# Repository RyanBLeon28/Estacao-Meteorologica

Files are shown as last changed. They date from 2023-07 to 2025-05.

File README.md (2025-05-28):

<h1>Estação Meteorológica Microcontrolada</h1>

<div align="center">
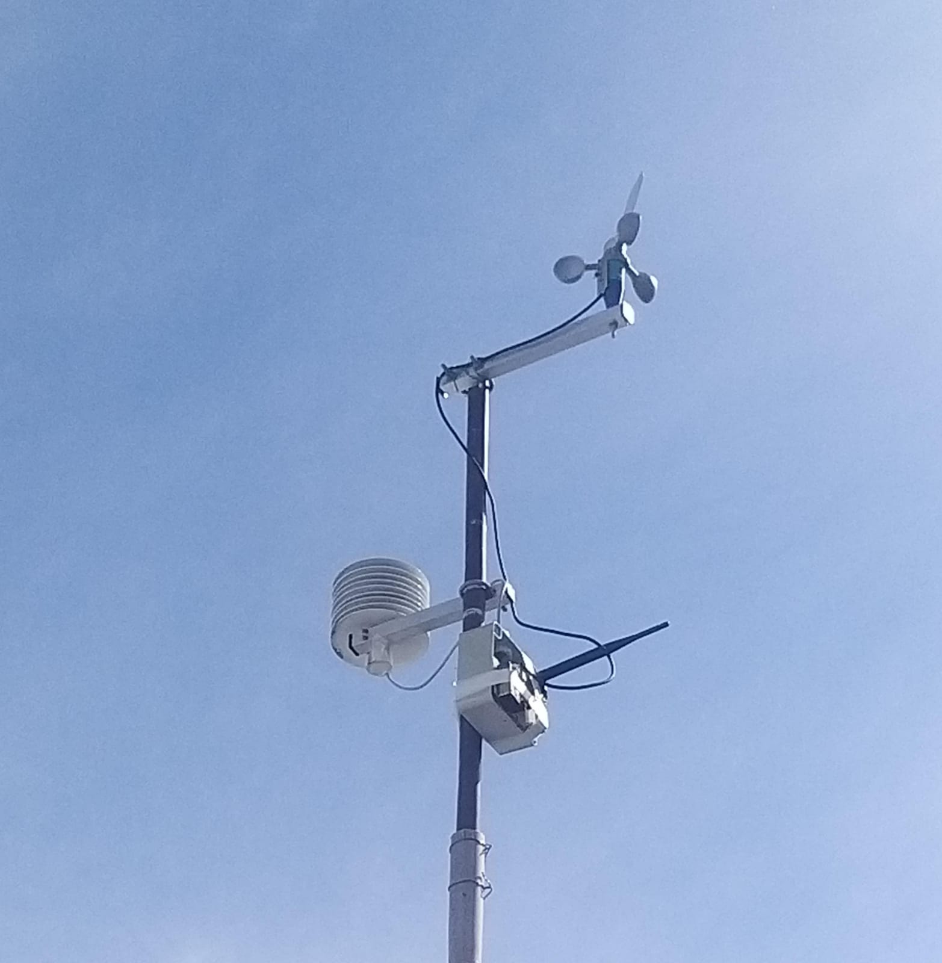
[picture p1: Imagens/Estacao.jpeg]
    
</div>

As estações meteorológicas são equipamentos utilizados para monitoramento e registro de condições climáticas por meio de sensores que analisam parâmetros atmosféricos como temperatura, umidade, pressão, velocidade e direção do vento. Neste projeto, os sensores estão conectados a um microcontrolador responsável por realizar a leitura dos dados. Esses dados são enviados automaticamente por protocolo LoRa(Long Range) para um servidor remoto (Datalogger), que realiza o armazenamento e processamento das informações.

O sistema foi projetado para operar continuamente e com baixo consumo de energia, sendo ideal para aplicações em ambientes externos. A visualização dos dados é feita por meio de dashboards acessíveis via navegador, possibilitando o acompanhamento em tempo real das variáveis monitoradas.

<h2>Tecnologias Utilizadas</h2>

<ul>
    <li><strong>MQTT (Eclipse Mosquitto):</strong> protocolo leve de comunicação utilizado para transmitir os dados dos sensores de forma eficiente e confiável.</li>
    <li><strong>Node.js:</strong> ambiente de execução utilizado no backend para processar as mensagens recebidas e integrá-las aos demais componentes do sistema.</li>
    <li><strong>Node-RED:</strong> ferramenta baseada em fluxo que facilita a criação de integrações entre os dados do MQTT e os bancos de dados utilizados.</li>
    <li><strong>InfluxDB:</strong> banco de dados especializado em séries temporais, utilizado para armazenar os dados dos sensores com alta performance.</li>
    <li><strong>Grafana:</strong> plataforma para visualização de dados que permite criar dashboards interativos e intuitivos para o acompanhamento das variáveis climáticas.</li>
</ul>

<h2>Detalhamento do projeto</h2>

<p>Para mais detalhes sobre o desenvolvimento da estação, incluindo a calibração de sensores como o anemômetro e a integração dos dados, consulte o <a href="Estação_Meteorológica_Microcontrolada.pdf" target="_blank">Relatório Descritivo do Projeto</a>.</p>

<h2>Referências</h2>

<p>
NODE.JS. Node.js. Disponível em: <a href="https://nodejs.org/en">https://nodejs.org/en</a>. Acesso em: 19 maio 2023.
</p>
<p>
MOSQUITTO. Mosquitto. Disponível em: <a href="https://mosquitto.org/">https://mosquitto.org/</a>. Acesso em: 19 maio 2023.
</p>
<p>
NODE-RED. Node-RED. Disponível em: <a href="https://nodered.org/">https://nodered.org/</a>. Acesso em: 19 maio 2023.
</p>
<p>
INFLUXDATA. Documentation. Disponível em: <a href="https://docs.influxdata.com/">https://docs.influxdata.com/</a>. Acesso em: 19 maio 2023.
</p>
<p>
GRAFANA LABS. Grafana. Disponível em: <a href="https://grafana.com/">https://grafana.com/</a>. Acesso em: 19 maio 2023.
</p>

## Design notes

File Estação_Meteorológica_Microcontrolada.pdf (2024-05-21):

Palavras-chave: Meteorologia, Anemômetro; IOT; DIY; Estação; Automatização.
INTRODUÇÃO
As estações meteorológicas são equipamentos para monitoramento e registro de condições climáticas com sensores configuráveis para análise de parâmetros atmosféricos e outras variáveis que afetam as rotinas meteorológicas. Os componentes podem ser: temperatura, umidade, pressão atmosférica, chuva, direção e velocidade do vento. Com os dados coletados e condições passadas, é possível calcular a probabilidade de eventos climatológicos de um futuro próximo.
A importância desses dados está ligada à previsão de como o clima pode se comportar em determinado local. Dessa forma, anteceder o que acontecerá é de extrema relevância, uma vez que se faz a necessidade em várias atividades humanas como a navegação, a aviação, a pesca, o setor energético, o gerenciamento de recursos hídricos, o turismo e a agricultura.
METODOLOGIA
O processo de coleta de dados acontece de forma automática - os sensores ligados a um microcontrolador receberão os dados e enviaram para um servidor (Datalogger). O modelo de estação automática no Brasil ainda é reduzido se comparado ao modelo convencional (um funcionário ir algumas vezes ao dia manualmente anotar os dados).
A parte instrumental do Anemômetro e Direção do vento foram produzidas em uma impressora 3D, a partir de um projeto pronto, adicionando rolamentos, imãs e parafusos.
Os sensores usados nesse projeto são, AS5600 (sensor de angulação), AH49E (sensor de efeito Hall), DTH11(sensor de temperatura e umidade) e BMP280 (sensor de pressão,altitude e temperatura).
Como microcontrolador, um ESP32 se comunica por protocolo MQTT com o servidor aberto, assim torna-se possível encaminhar e armazenar os dados coletados para um monitoramento remoto.

1


Figure 1: Estação meteorológica. Fonte:

2

## Contents

1 Instrumentação | 4
2 Gerenciamento dos Dados | 13

3

## 1 Instrumentação

### 1.1 Anemometro

Como o anemômetro é um instrumento para medir a velocidade do vento, o que garante sua precisão é de acordo com sua calibração. Para calibrarmos, utilizamos um anemômetro já calibrado, o Vaavud. Esse equipamento possui um aplicativo que detecta a passagem de um imã dentro do anemômetro. Como o celular possui um sensor magnético, consegue captar qual a frequência dos pulsos. Dessa forma, foi utilizado para servir de parâmetro para calibração.

### 1.1.1 Estrutura de Calibração

Para calibrarmos com o outro equipamento, montamos uma estrutura em impressora 3D em que os dois anemômetros ficassem no mesmo eixo. Como os estam presos no mesmo eixo, têm a mesma frequência angular. Sendo assim, usando um tacômetro DT-2234C capturamos a Rotação Por Minuto(RPM). Dessa forma, podemos ter a frequência angular, que pode ser usada para achar a velocidade do objeto.
Para a precisão da linearidade da velocidade e das amostras foi usado um motor, sendo controlado por um modulador PWM com 555.

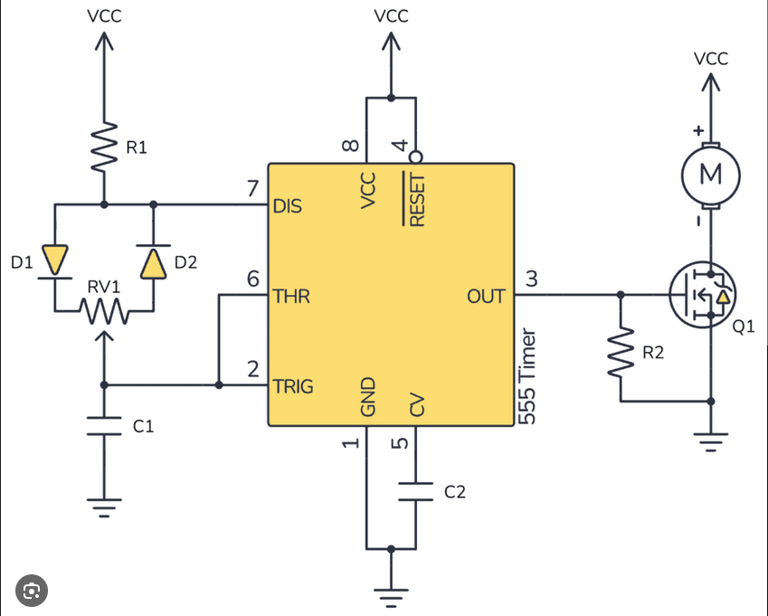
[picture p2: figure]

Figure 2: Modulador PWM com 555. Fonte:

Essa foi a primeira estrutura montada para começo da coleta de amostras. Com o decorrer das amostras, foi analisado a imprecisão, pois o Trimpot usado para controlar o DutyCicle, era simples e não tinhamos a mesma velocidade de saída para todas as amostras.

4

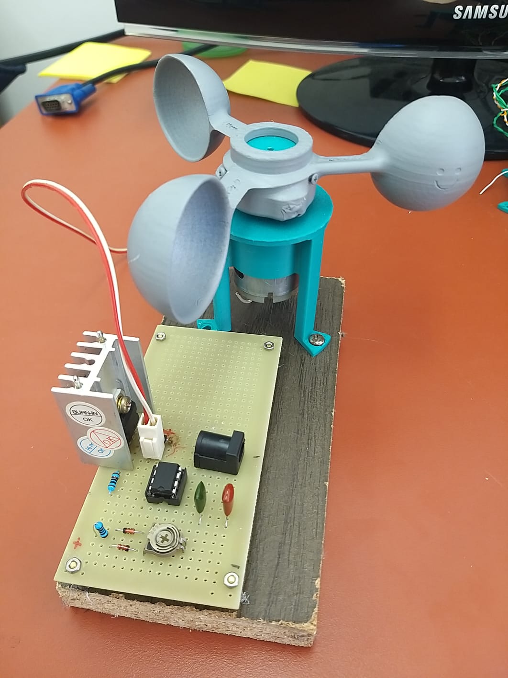
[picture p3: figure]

Figure 3: Modulador PWM com 555. Fonte:

Dessa forma, trocamos por um Trimpot de Precisão, de 0kOhm a 10kOhm. Dessa forma, controlamos a resistência que estava sendo aplicada e padronizamos isso durante a calibração.

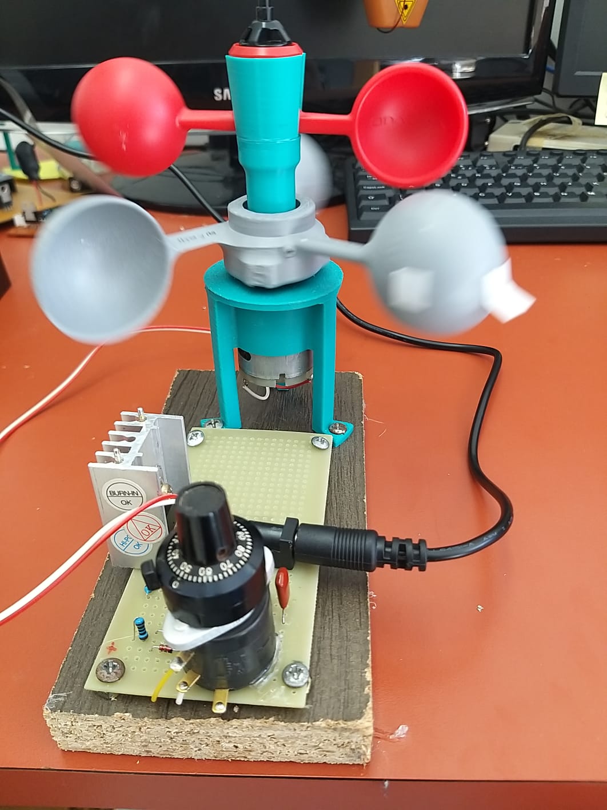
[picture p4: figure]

Figure 4: Modulador com o Trimpot de Precisão. Fonte:

5

### 1.1.2 Sensor Magnético

Para marcar a frequência do anemômetro, é utilizado um sensor magnético, que capta os pulsos de tensão de um imã, neste anemômetro há três imãs, um em cada pá. Nesse projeto, o sensor magnético escolhido foi o Sensor AH49E de efeito Hall (que descreve a geração de uma diferença de potencial elétrico (tensão) em um condutor quando uma corrente elétrica é aplicada perpendicularmente a um campo magnético externo).
Como o anemômetro possui três pás, são usados três imãs, no mesmo eixo das pás. E para contar um volta, é medido o número de pulsos e dividido pela quantidade de imãs.
Como o sensor de efeito Hall pode perder alguns dos pulsos ou não pegar com pouca intensidade o sinal, fizemos um sistema para que o sinal recebido fosse amplificado para uma leitura mais precisa. Sendo assim, foi desenvolvida uma PCB no software Kicad.

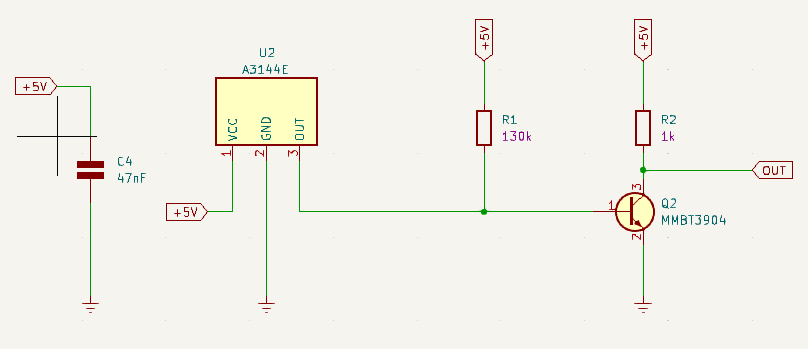
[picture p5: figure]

Figure 5: Esquemático sensor magnético. Fonte:

Figure 6: Visão 3D sensor magnético. Fonte:

6

### 1.1.3 Coleta de amostras

A coleta foi feita de forma manual com os seguintes passos, em um código python recebia a quantidade de amostras desejadas, em seguida, para a amostra de número um, inseria-se o valor da resistência utilizada no Trimpot, velocidade (em m/s no aplicativo do anemômetro do Vaavud), e cinco amostras de RPM refentes a essa resistência e velocidade. Sendo assim, com mais amostras era feita a média delas, para que fosse mais precisa.
Feita de forma mecânica e padronizando uma sequência na coleta para que as amostras obtidas tivessem as mesmas condições.
A imagem a seguir mostrar como eram feitas as coletas. O celular estava marcando a velocidade em m/s do anemômetro Vaavud, e com o tacômetro era lida a RPM.

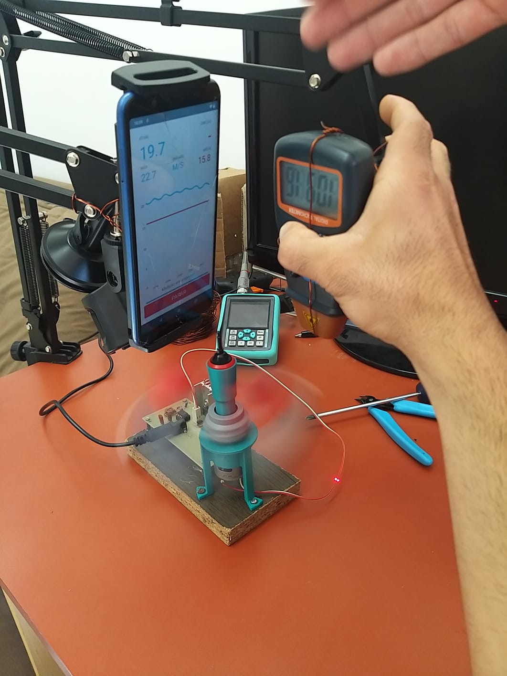
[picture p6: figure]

Figure 7: Coleta de amostras. Fonte:

Como os dados podiam sofrer alguma alteração, pois ao apertar com a mão o tacômetro e o tempo de leitura e angulação do laser na fita poderiam mudar, para que isso melhorasse, usamos um botão externo para acionar o tacômetro e para valor regulado do Trimpot de precisão, recebia uma leitura da velocidade e cinco amostras de RPM, tentando manter o mesmo padrão, entre visualizar e digitar.

7

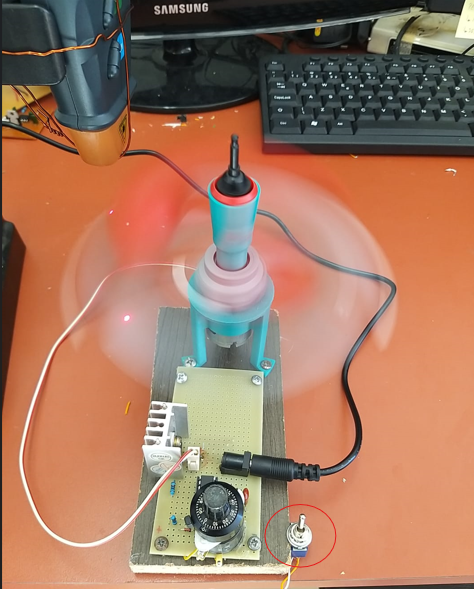
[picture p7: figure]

Figure 8: Tacômetro dom botão. Fonte:

### 1.1.4 Tratamento dos dados

Como citado anteriormente, os anemômetros estão girando no mesmo eixo, dessa forma, possuem mesma velocidade e, consequentemente, mesma frequência angular.
Depois de uma coleta de 120 amostras (excluindo as amostras que foram coletadas antes da última versão da estrutura de calibração), entre 0m/s à 21m/s, tendo como valor mínimo de 25,60rad/s e como máximo 110,93rad/s, frequência angular média de 71,96rad/s e apresentou Desvio Padrão de 23,61. Portanto, como apresentou certa linearidade, não precisamos retirar valores que fossem muito extremos ou que fugissem da reta.
Com as amostras coletadas foi feita uma regressão linear, da velocidade em relação a frequência angular. O valor resultante da equação da reta da regressão linear: Velocidade = 0.17117843*(Frequência Angular) + 0.19744649996588137.

8

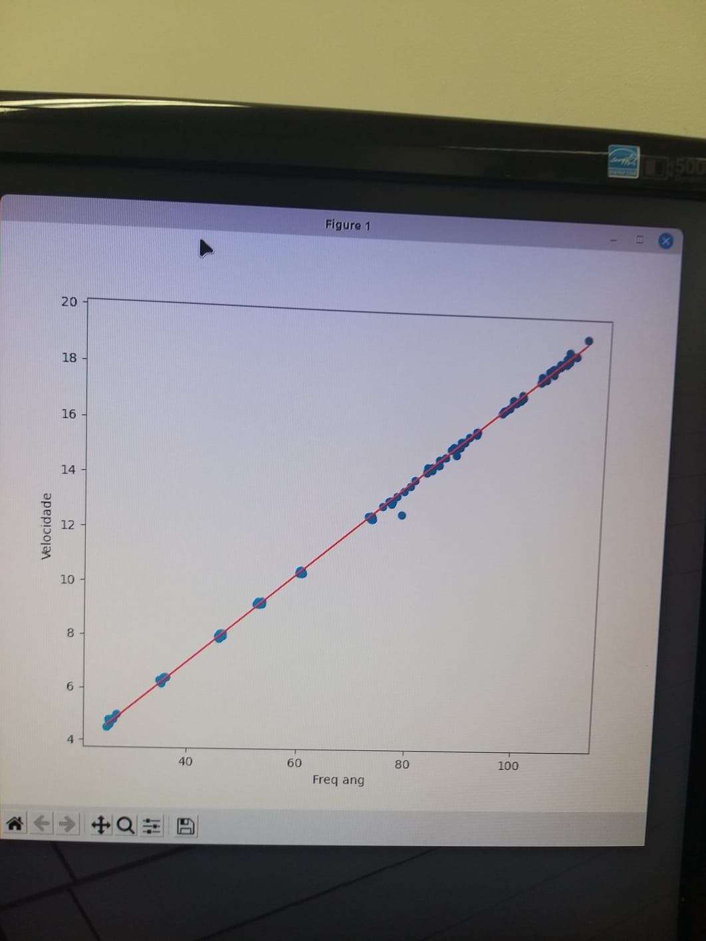
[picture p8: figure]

Figure 9: Regressão linear entre frequência angular e velocidade. Fonte:

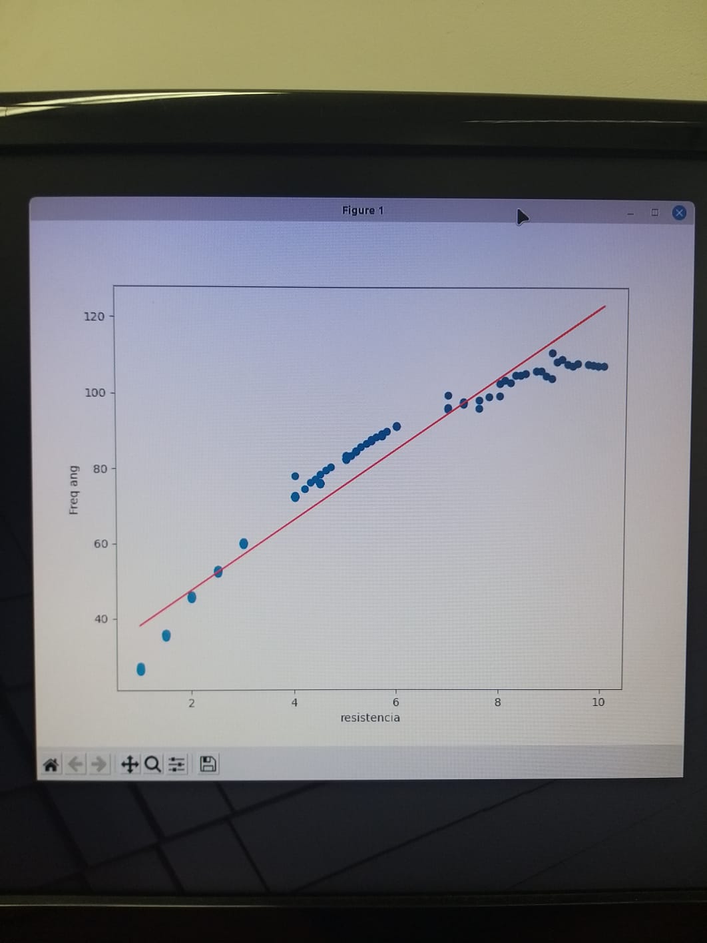
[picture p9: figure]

Figure 10: Regressão linear entre resistência e frequência angular. Fonte:

### 1.1.5 Resultados do Anemômetro

Com o resultado da regressão linear, obtendo o Rotação Por Minuto (RPM) é possível calcular a frequência angular e, assim, a velocidade em m/s. O código usado para o tratamento da coleta de pulsos com o sensor de

9

efeito Hall, está disponibilizado em nosso github. Explicando breviamente o código, é feita uma interrupção em uma porta digital do arduino quando a uma borda de subida, ou seja, um pulso elétrico captado pelo sensor. A cada três pulsos é contado como uma volta completa.
Para suavização das amostras, pode ser definido a quantidade de amostras que será feita a média da velocidade. Assim, há uma vetor tem tamanho definido conforme a quantidade inserida como máximo de amostras.
Na imagem a seguir, é mostrado o arduino Nano mostrando o RPM em um display Oled, colocados na mesma PCB em que é controlado o motor para velocidade do anemômetro.

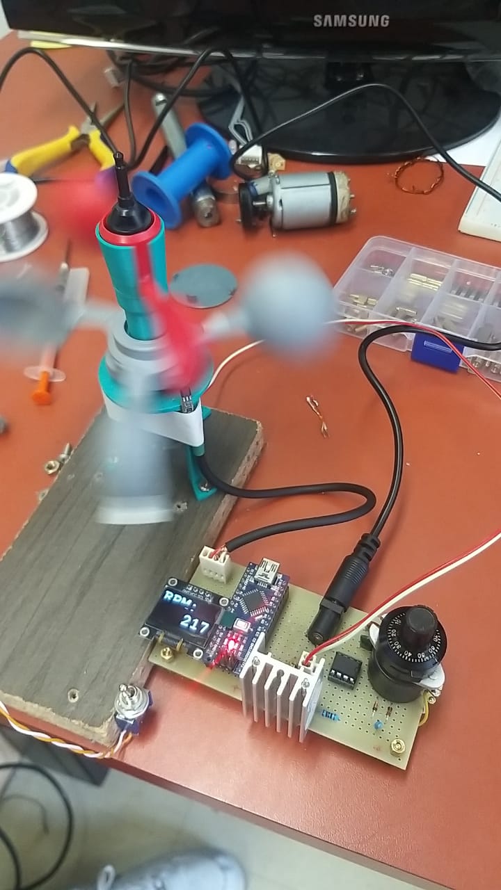
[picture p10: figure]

Figure 11: . Fonte:

10

### 1.2 Sensores

Além do sensor magnético, foram usados sensores para outros dados meteorológicos, como temperatura, umidade, pressão e altitude.Para temperatura e umidade o sensor DHT11, usando sinal digital em sua saída. E, também, o sensor BMP280 como objetivo principal, medir a pressão atmosférica, e com base nesses dados determinar com precisão a altitude de um ambiente, além de ser capaz de medir temperatura, este utiliza comunicação I2C.

### 1.3 Microcontrolador

Como microcontrolador usamos o Arduino Uno para calibração do anemômetro e alguns testes rápidos, pela versatilidade, compatibilidade e abundância de recursos que essa placa entrega.
Como a estação pode estar em lugares remotos, para enviar seus dados é necessária a comunicação com a internet, sendo assim, usamos o microocontrolador ESP32, que já possui wifi e bluetooth integrado. Além de outras vantagens em relação ao Arduino Uno, como maior poder de processamento, tendo dois núcleos,clock significativamente maior e memória.

11

### 1.4 LoRa

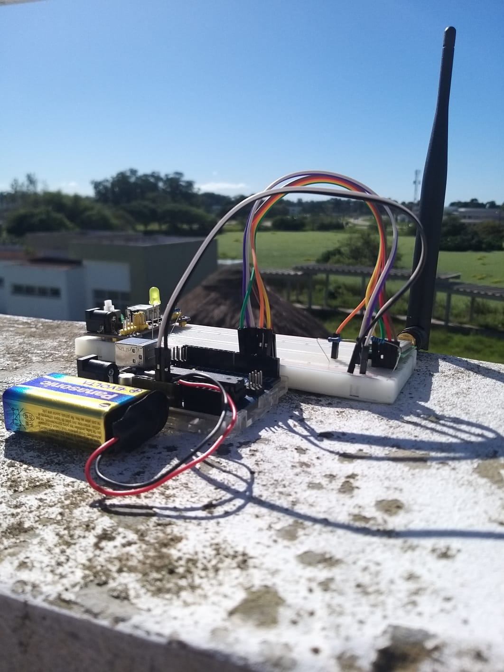
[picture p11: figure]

Figure 12: Estação meteorológica. Fonte:

Em alguns casos, podemos ter estações em lugares remotos, dessa forma, é importante haver uma comunicação estável e que não dependa de rede. Com isso, pode ser implementado a comunicação de radiofrequência. Nesse caso, a comunicação LoRa(Long Range) com longo alcance e baixa potência, projetada para aplicações de Internet das Coisas(IOT) e M2M(Machine-to-Machine). A vantagem dessa tecnologia é o baixo consumo de energia, umas de suas funções, apesar do baixo consumo, é a capacidade de ativar o modo Sleep (dormir) e quando solicitado voltar a funcionar e enviar os dados solicitados. Isso se torna ainda mais eficaz quando é usado o módulo LoRa para aplicações alimentadas por baterias.
Há vários modelos no mercado com muitas possibilidades de alcances, para o projeto usamos o módulo LoRa, o módulo usado é o modelo E220-900T22D, com capacidade de até 5km e frequência de 900MHz.
Por exemplo, uma estação com um microcontrolador arduino Nano coletar as informações dos sensores e enviar via LoRa para uma estação também com LoRa e um ESP32 que tem Wifi integrado para mandar os dados para o banco de dados na nuvem.
No projeto estamos enviando uma estrutura com os dados coletados em uma estação e sendo enviados para outra, como no exemplo anterior.

12

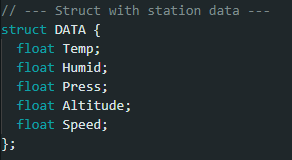
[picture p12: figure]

Figure 13: Estrutura sendo enviada via LoRa.

## 2 Gerenciamento dos Dados

Para que a estação meteorológica seja automatizada, precisa que seus dados sejam tratados e armazenados em algum lugar. Então, mesmo a estação estando em lugares remotos ou não, há a necessidade de que esteja preparada para enviar seus dados por meio de algum protocolo para um banco de dados. Dessa forma, essas informações podem ser usadas em previsões climáticas futuras.

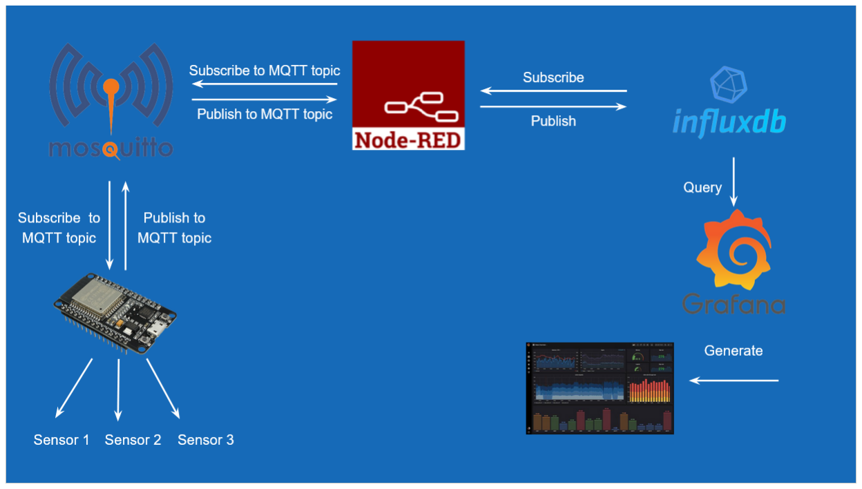
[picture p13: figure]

Figure 14: Esquemático do gerenciamento entre as aplicações.

### 2.1 Conexão MQTT

Após os dados estarem no microcontrolador, com a função de wifi do ESP32, usamos o protocolo de comunicação MQTT(Message Queuing Telemetry Transport) é um protocolo de mensagens leve e eficiente, projetado para comunicação entre dispositivos em redes de IoT (Internet das Coisas) ou em redes de comunicação com largura de banda limitada. Desenvolvido pela IBM nos anos 1990, o MQTT tornou-se um padrão aberto e é amplamente utilizado em uma variedade de aplicações IoT devido à sua simplicidade, eficiência e confiabilidade.
Usar um Broker MQTT facilita a comunicação entre dispositivos na arquitetura de mensagens, pois atua como um intermediário centralizado na comunicação entre dispositivos. Ademais, o gerenciamento de tópicos, broker MQTT

13 facilita o gerenciamento de tópicos e assinaturas. Ele permite que os dispositivos publiquem mensagens em tópicos específicos e que outros dispositivos subscrevam a esses tópicos para receber as mensagens. Isso simplifica a organização e o controle da comunicação em uma rede de dispositivos.
No contexto apresentado, utilizamos o broker Mosquitto, um servidor MQTT de código aberto. Desenvolvido pela Eclipse Foundation, o Mosquitto é reconhecido como uma escolha amplamente adotada para implementações de IOT e outras aplicações que requerem comunicação baseada nesse protocolo.

14

### 2.2 Node Red

O Node Red é um software para programar por meio de fluxogramas, utilizando Nodejs. Usa-se nodos para conectarem entre si.

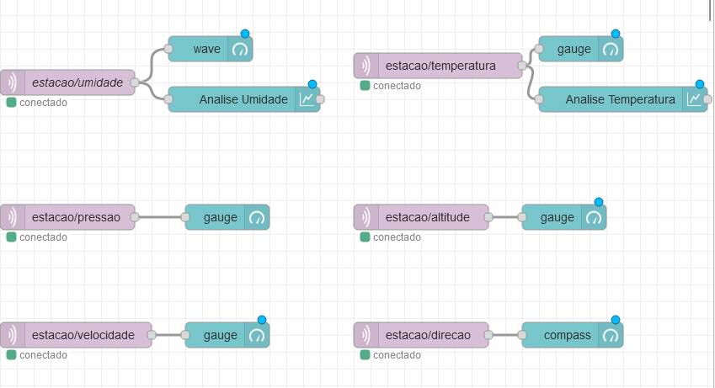
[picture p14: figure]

Figure 15: Nodos Node Red. Fonte:

Para configurar a comunicação com o banco de dados Influxdb e para criar uma dashboard do próprio Node Red, foram adicionadas as paletas nodered-contrib-influxdb e node-red-dashboard.
Como servidor foi usado o test.mosquitto.org:1883, esse é o servidor aberto do Broker Mosquitto. Como é um servidor aberto para uso de protocolo MQTT, o site recomenda não ser usado para aplicações grandes, porém, se for necessário maior resposta e do servidor, recomendasse utilizar um servidor privado.
O Tópico é o nome que será usado para acessar a informação publicada. Como exemplo, estação/temperatura.

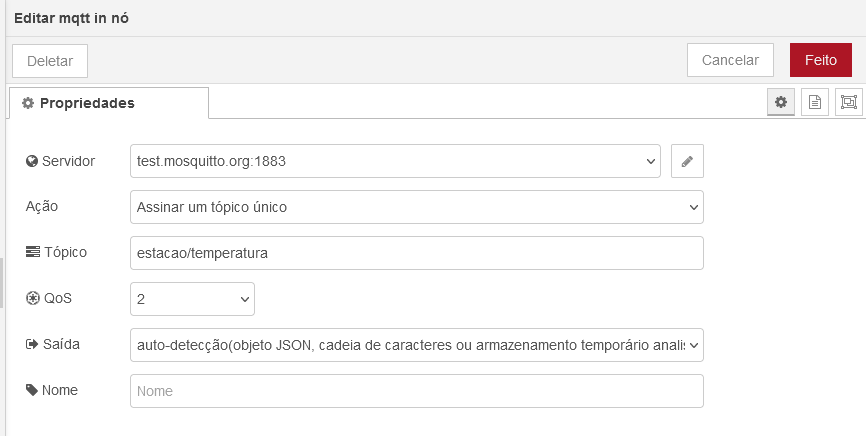
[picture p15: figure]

Figure 16: Configurando tópico Node Red. Fonte:

### 2.3 Influxdb

O InfluxDB foi o banco de dados usado para armazenamento das informações. Muito utilizado para series temporais, o InfluxDB se encaixa muito bem para controlarmos os dados da estação meteorológica.
O banco de dados está rodando localmente na porta 8086 de um computador com sistema operacional linux, MINT 21.3.

15

### 2.3.1 Instalar InfluxDB

Para instalar o InfluxDB em sua máquina, use os seguintes comando no seu terminal:

Para instalar o InfluxDB:
$curl -O https://download.influxdata.com/influxdb/releases/influxdb22.7.6− 1amd64.deb
$sudodpkg − iinfluxdb22.7.6 − 1amd64.deb

Para rodar o InfluxDB:
$influxd
O programa já estará rodando localmente, em seu navegador acesse: htpps://localhost:8086/

### 2.3.2 Configuração do InfluxDB

Em seu perfil criará uma Organization, depois será necessario gerar um Token para dar permição ao Node-Red enviar os dados. Após ter o token, crie um Bucket, local onde ficarão os dados recebidos, no nosso exemplo o nome do Bucket é estacaoMeteorologica.

16

### 2.4 Grafana

Para instalar o Grafana em sua máquina, use os seguintes comando no seu terminal:

Para instalar o Grafana:
$ sudo apt update
$ sudo apt-get install -y adduser libfontconfig1 musl
$ wget https://dl.grafana.com/enterprise/release/grafana-enterprise10.4.2amd64.deb $sudodpkg − igraf ana − enterprise10.4.2amd64.deb
$sudosystemctlenablegraf ana − server
$sudosystemctlstartgraf ana − server

Para checar se está tudo dando certo:
O programa já estará rodando localmente, em seu navegador acesse: htpps://localhost:3000/

A dashboard para vizualição pode ser personalizada.

17

Referências:
NODE.JS. Node.js. Disponível em: https://nodejs.org/en. Acesso em: 19 maio 2023.
MOSQUITTO. Mosquitto. Disponível em: https://mosquitto.org/. Acesso em: 19 maio 2023.
NODE-RED. Node-RED. Disponível em: https://nodered.org/. Acesso em: 19 maio 2023.
INFLUXDATA. Documentation. Disponível em: https://docs.influxdata.com/. Acesso em: 19 maio 2023.
GRAFANA LABS. Grafana. Disponível em: https://grafana.com/. Acesso em: 19 maio 2023.

18

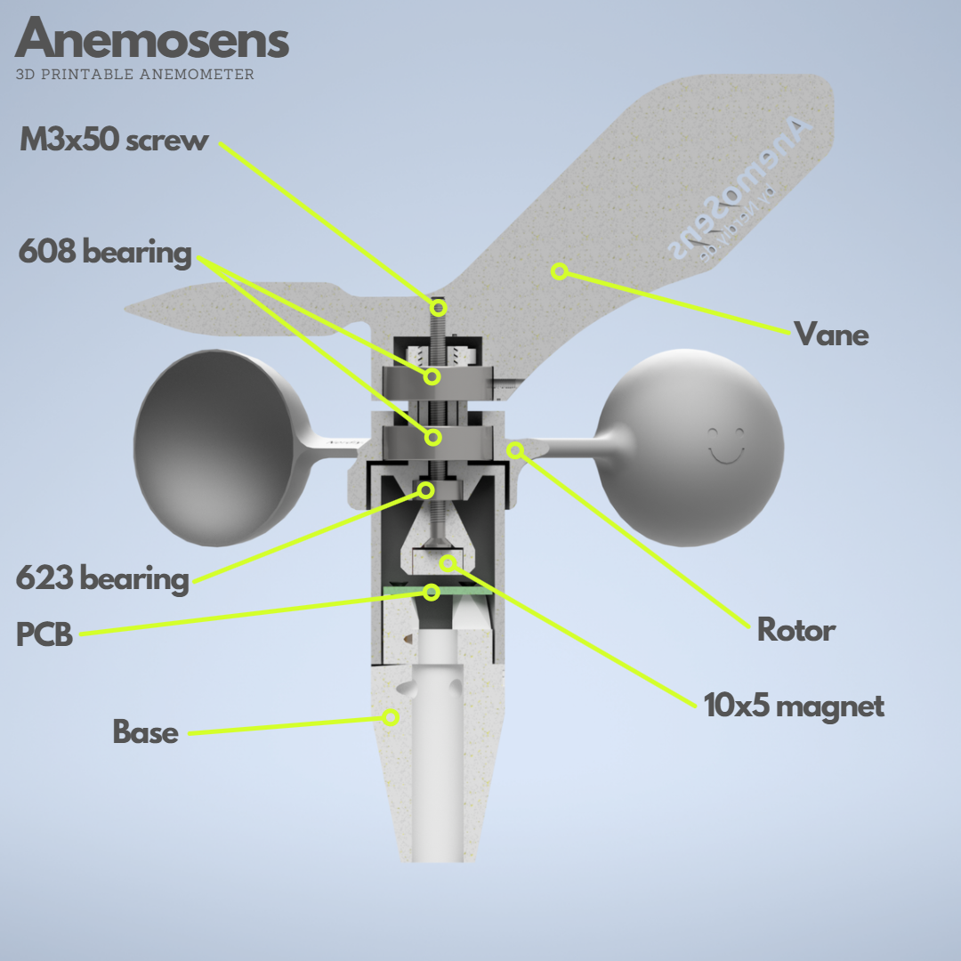
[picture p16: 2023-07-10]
Anemometro/Sensor de Efeito Hall PCB/Anemosens-main/pictures/Anemosens_overview.png

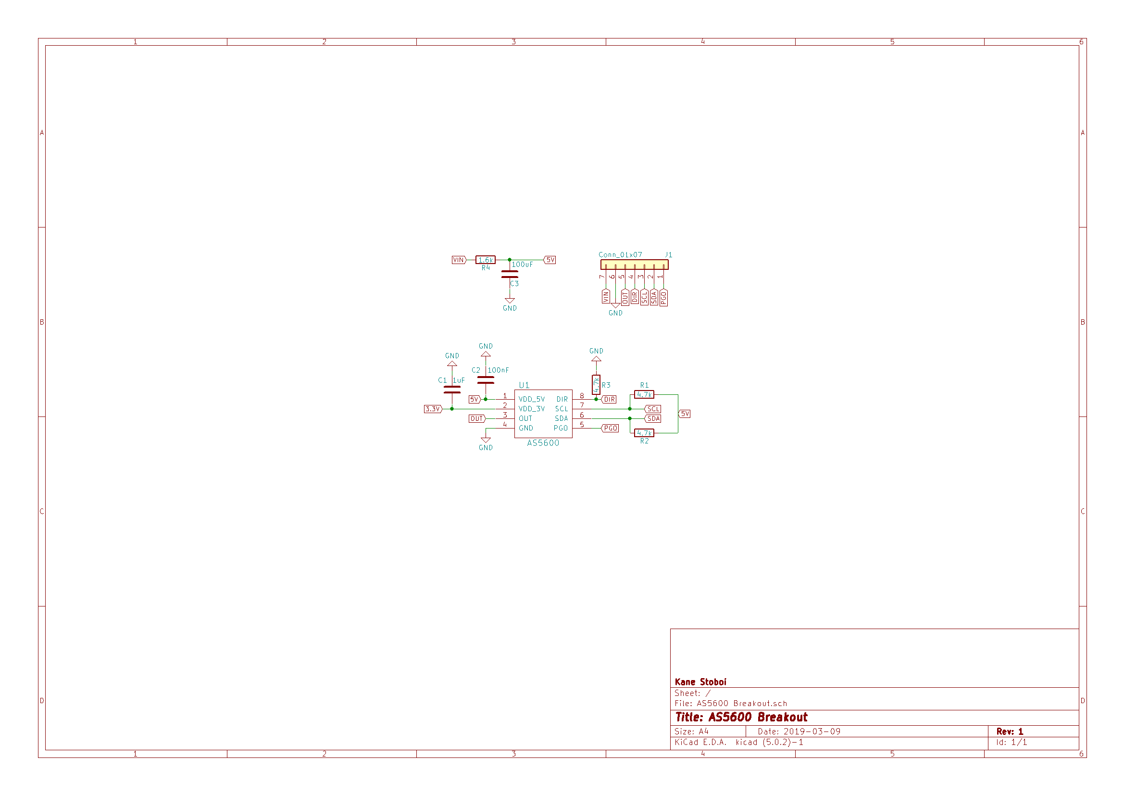
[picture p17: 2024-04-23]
Sensores/SensorAS5600/AS5600_PCB/AS5600 Board Schematic.png

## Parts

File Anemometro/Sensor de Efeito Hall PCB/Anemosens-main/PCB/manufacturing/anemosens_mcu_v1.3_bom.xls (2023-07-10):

PCBWay Bom Quotation, Product No.:T-1C4W457044A
Item # | *Designator | *Qty | Manufacturer | *Mfg Part # | Description / Value | *Package/Footprint | *Unit Price(5 sets) | *Total | *Delivery Time | *Actual Purchase Mfg Part # | *PCBWay Note | Customer Reply | PCBWay Update | Comment
1 | C2,C3,C9,C10,C102,C107,C125 | 7 |  |  | 100nF | C0805K | $0.031 | $1.085 |  | CL21B104KCFNNNE | 『 』
2 | C47,C48,C101,C103 | 4 |  |  | 1µF | C0805K | $0.029 | $0.580 |  | CL21B105KBFNNNE | 『 』
3 | C1,C6 | 2 |  |  | 10uF | C0805K | $0.060 | $0.600 |  | CL21A106KOQNNNE | 『 』
4 | C7,C8 | 2 |  |  | 22pF | C0805K | $0.074 | $0.740 |  | CL21C220JBANNNC | 『 』
5 | C11 | 1 |  |  | 1nF | C0805K | $0.242 | $1.210 |  | CL21C102JBCNNNC | 『 』
6 | R1,R7 | 2 |  |  | 10k | R0805W | $0.030 | $0.300 |  | RC0805FR-0710KL | 『 』
7 | R4,R6 | 2 |  |  | 5,1k | R0805W | $0.031 | $0.310 |  | RC0805FR-075K1L | 『 』
8 | R10,R11 | 2 |  |  | 66 | R0805W | $0.031 | $0.310 |  | RC0805FR-0766RL | 『 』
9 | R13,R14 | 2 |  |  | 5k | R0805W | $0.031 | $0.310 |  | RC0805FR-075KL | 『 』
10 | R15,R16 | 2 |  |  | 4k7 | R0805W | $0.035 | $0.350 |  | RC0805FR-074K7L | 『 』
11 | R45,R47 | 2 |  |  | 470 | R0805W | $0.032 | $0.320 |  | RC0805FR-07470RL | 『 』
12 | R3 | 1 |  |  | 120 | R0805W | $0.066 | $0.330 |  | RC0805FR-07120RL | 『 』
13 | R12 | 1 |  |  | 12k | R0805W | $0.050 | $0.250 |  | RC0805FR-0712KL | 『 』
14 | D10 | 1 | MDD | SS34 | SS34 | SMADIODE | $0.110 | $0.550 |  |  | 『 』
16 | U36 | 1 |  | BME280 | BME280 | PSON65P250X250X100-8N | $7.700 | $38.500 |  |  | 『 』[Price is changing higher, final price should be subjected to the real price when order!] |  |  | Optional: Only needed if measurement of temperature, humidity and air pressure is needed
17 | U$22,U$23 | 2 |  |  | SMT2X4MMTACTILE_PUSH_BUTTON | SMT2X4MMTACTILE_PUSH_BUTTON |  |  |  |  | 『 』Please provide exact part number or component URL. |  |  | Optional: Only needed if programming of the ESP32 is done manually (not via the USB-C connection)
18 | U6 | 1 |  | MAX3485ESA+ | MAX3485ESA+ | SOIC127P600X175-8N | $1.470 | $7.350 |  |  | 『 』 |  |  | Optional: Only needed if communication via rs485/modbus is needed
19 | U34 | 1 |  | DS3232M | DS3232M | SOIC127P600X175-8N | $9.500 | $47.500 |  |  | 『 』[Price is changing higher, final price should be subjected to the real price when order!] |  |  | Optional: Only needed for Timekeeping if data logging on locally connected micro SD card is needed
20 | U1 | 1 |  | CH340G | CH340G | SOIC16 | $0.825 | $4.125 |  |  | 『 』
21 | U2 | 1 |  | UMH3N | UMH3N | SOP65P210X100-6N | $0.156 | $0.780 |  |  | 『 』
22 | U17,U20 | 2 |  | RT9013 | RT9013 | SOT23-5 | $0.417 | $4.170 |  | RT9013-33GB | 『 』
23 | U3 | 1 |  | ESP32-WROVER-B | ESP32-WROVER-B | XCVR_ESP32-WROVER-B_(16MB) | $5.360 | $26.800 |  | ESP32-WROVER-B(16MB) | 『 』[Price is changing higher, final price should be subjected to the real price when order!]
24 | Y1 | 1 |  | ABM8AIG-12.000MHZ-12-2Z-T3 | ABM8AIG-12.000MHZ-12-2Z-T3 | OSCSC320X250X100N | $1.308 | $6.540 | 7-10 Workdays |  | 『 』
25 | F1 | 1 |  | 1206L200PR | 4A | PTC-1206-WIDE |  |  |  |  | 『 』
26 | EXT1 | 1 |  | SM04B-SRSS-TB(LF)(SN) | MICROBUILDER_STEMMA_I2C_QT | JST_SM04B-SRSS-TB(LF)(SN) |  |  |  |  | 『 』
28 | IC2 | 1 | TECH PUBLIC | SRV05-4 | SRV05-4 | TSOP-6.PAC | $0.152 | $0.760 |  |  | 『 』
29 | J4 | 1 |  | USB4105_REVA | USB4105_REVA | GCT_USB4105_REVA | $1.059 | $5.295 | 7-10 Workdays | USB4105-GF-A | 『 』
30 | J2 | 1 |  | SM04B-SRSS-TB(LF)(SN) | SM04B-SRSS-TB(LF)(SN) | JST_SM04B-SRSS-TB(LF)(SN) | $0.260 | $1.300 |  |  | 『 』 |  |  | Optional: Only needed if communication via rs485/modbus is needed
31 | J1 | 1 |  | SM06B-SRSS-TB(LF)(SN) | SM06B-SRSS-TB(LF)(SN) | JST_SM06B-SRSS-TB(LF)(SN) | $0.552 | $2.760 |  |  | 『 』
32 | J6 | 1 |  | BC501SM-TR | BC501SM-TR | MPD_BC501SM-TR | $1.714 | $8.570 | 7-10 Workdays |  | 『 』
33 | J5 | 1 |  | MEM2067-02-180-00-A | TRANSFLASH-LOCK | TRANSFLASH-LOCK-SOCK |  |  |  |  | 『 』 |  |  | Optional: Only needed if data logging on a locally inserted sd card is needed.
 |  |  |  |  |  |  | All Total | $161.695

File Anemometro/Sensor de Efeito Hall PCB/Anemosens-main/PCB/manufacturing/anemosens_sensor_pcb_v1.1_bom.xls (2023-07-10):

PCBWay Bom Quotation, Product No.:T-1C6W457044A
Item # | *Designator | *Qty | *Mfg Part # | Description / Value | *Package/Footprint | *Unit Price(5 sets) | *Total | *Delivery Time | *Actual Purchase Mfg Part # | *PCBWay Note | Customer Reply | PCBWay Update | Comment
1 | C1,C7 | 2 |  | 100nF | C0805K | $0.032 | $0.320 |  | CL21B104KBCNNNC | 『 』
2 | C8 | 1 |  | 10uF | C0805K | $0.121 | $0.605 |  | CL21A106KOQNNNE | 『 』
4 | U1 | 1 | AS5048B-HTSP | AS5048B-HTSP | SOP65P640X120-14N | $9.718 | $48.590 | 7-10 Workdays |  | 『 』
5 | U2 | 1 | AH49E | AH49E | SOT91P240X105-3N | $0.228 | $1.140 |  |  | 『 』
6 | JP1,JP2 | 2 |  |  | 1X03 |  |  |  |  | 『 』Please provide exact part number or component URL. |  |  | Do not populate! This are solder pads only used for development purposes. (Same signals are available on J1)
7 | J1 | 1 | BM06B-SRSS-TB(LF)(SN) | BM06B-SRSS-TB(LF)(SN) | JST_BM06B-SRSS-TB(LF)(SN) | $0.437 | $2.185 |  |  | 『 』
 |  |  |  |  |  | All Total | $52.840

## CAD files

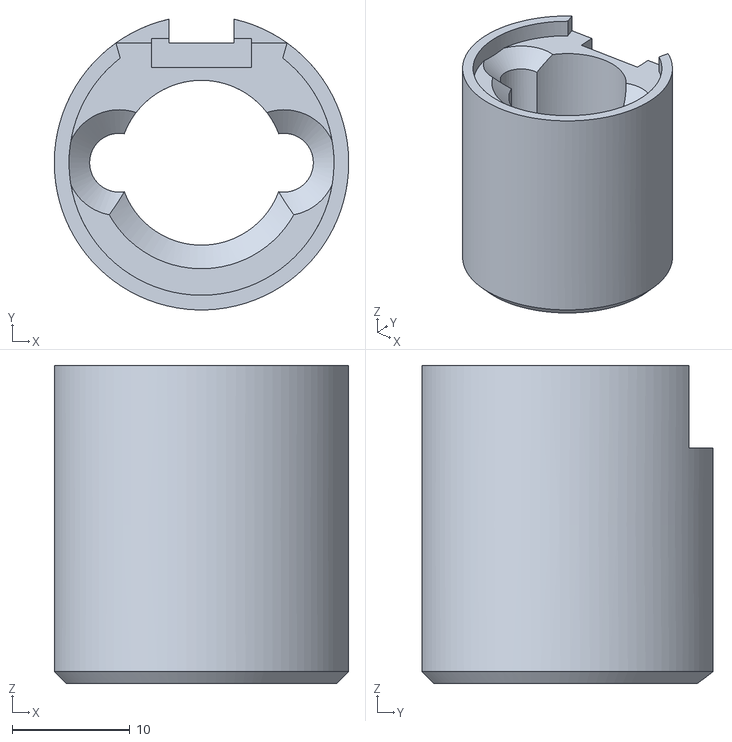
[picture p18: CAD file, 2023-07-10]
Anemometro/Sensor de Efeito Hall PCB/Anemosens-main/STLs/pcb_assembly_jig_V1.0.stl
25.0 x 24.7 x 27.0

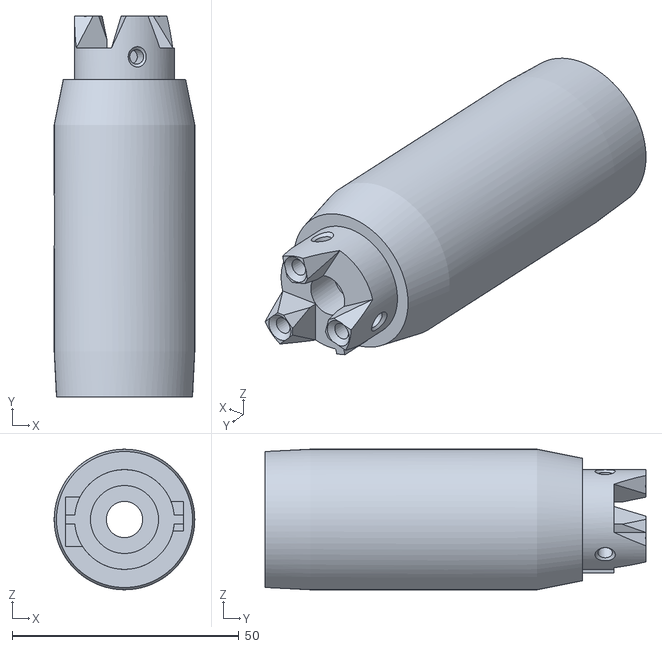
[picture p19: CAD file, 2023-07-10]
Anemometro/Sensor de Efeito Hall PCB/Anemosens-main/STLs/mount_base_mcu_board_V1.1.stl
31.0 x 84.0 x 31.0

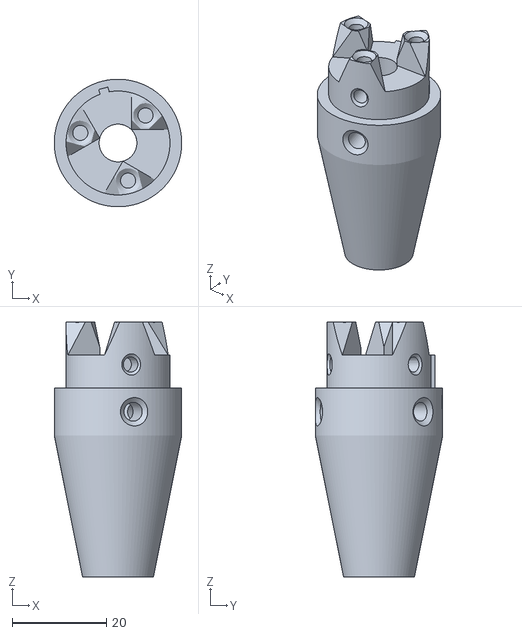
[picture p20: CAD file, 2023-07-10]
Anemometro/STLs/mount_base_10mm_pipe_fdm_printed_V1.0.stl
27.0 x 27.0 x 54.0

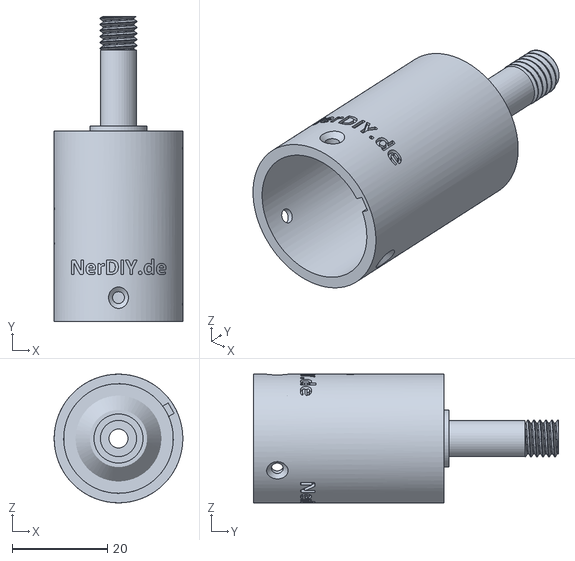
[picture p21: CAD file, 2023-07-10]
Anemometro/Sensor de Efeito Hall PCB/Anemosens-main/STLs/base_V1.1.stl
27.0 x 64.0 x 27.0

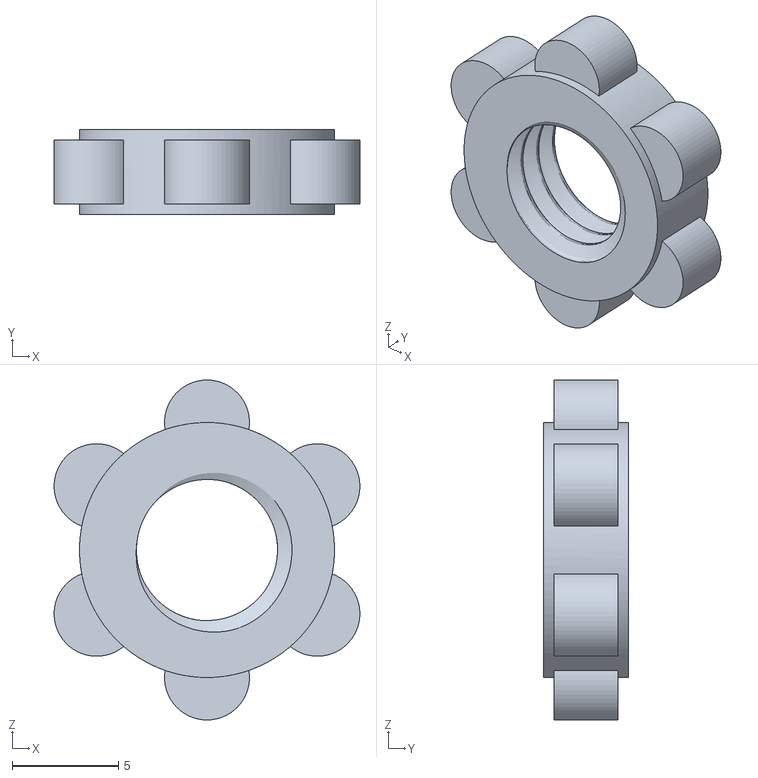
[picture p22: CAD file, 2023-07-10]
Anemometro/STLs/bearing_clamp_V1.0.stl
14.4 x 4.00 x 16.0

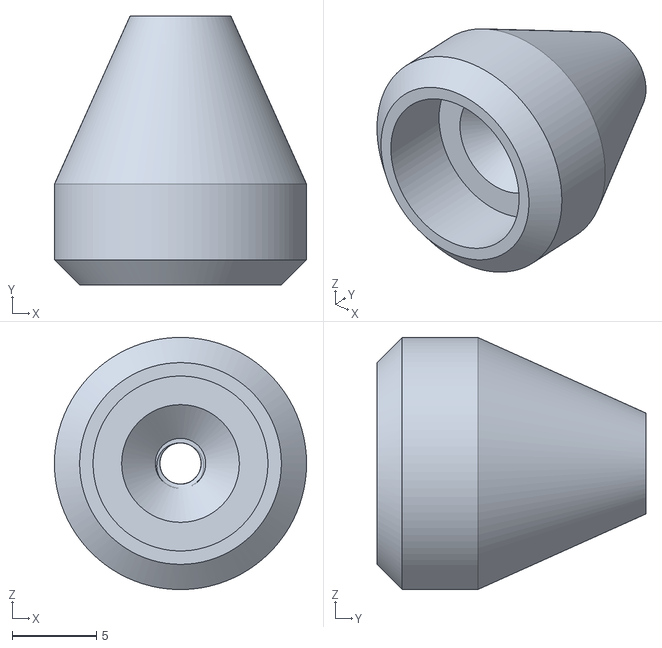
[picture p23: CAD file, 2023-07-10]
Anemometro/Sensor de Efeito Hall PCB/Anemosens-main/STLs/dir_magnet_base_V1.0.stl
15.0 x 16.0 x 15.0

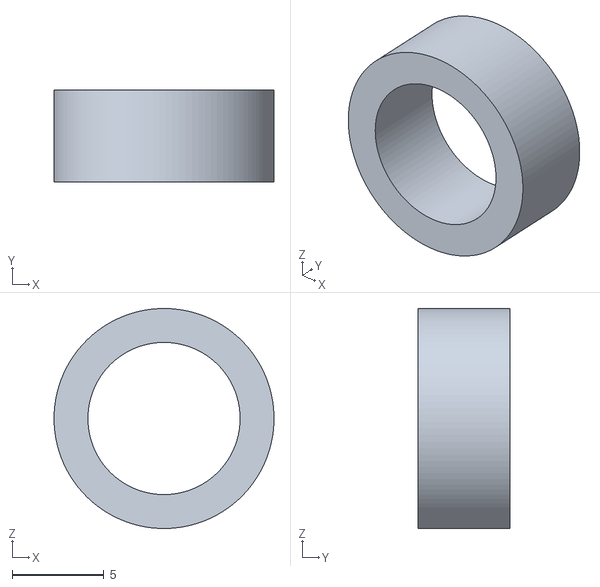
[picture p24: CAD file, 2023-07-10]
Anemometro/STLs/dir_sens_bearing_distance_ring_V1.0.stl
12.0 x 5.00 x 12.0

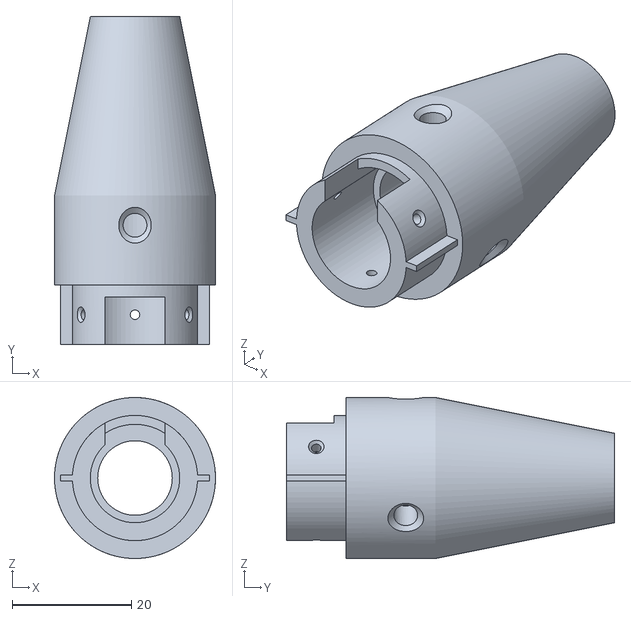
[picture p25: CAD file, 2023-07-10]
Anemometro/Sensor de Efeito Hall PCB/Anemosens-main/STLs/mount_base_mcu_board_bottom_cap_fdm_printed_V1.0.stl
27.0 x 55.0 x 27.0

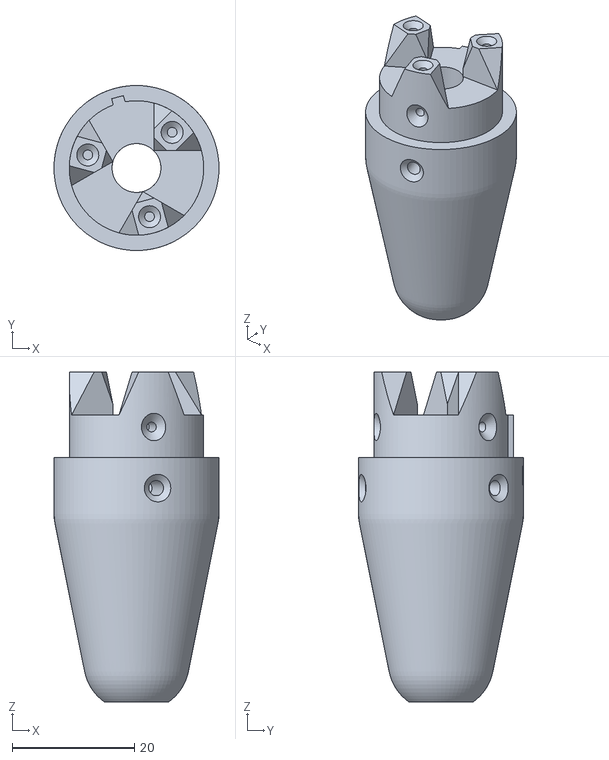
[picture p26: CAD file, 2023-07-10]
Anemometro/STLs/mount_base_10mm_pipe_sla_printed_V1.0.stl
27.0 x 27.0 x 54.0

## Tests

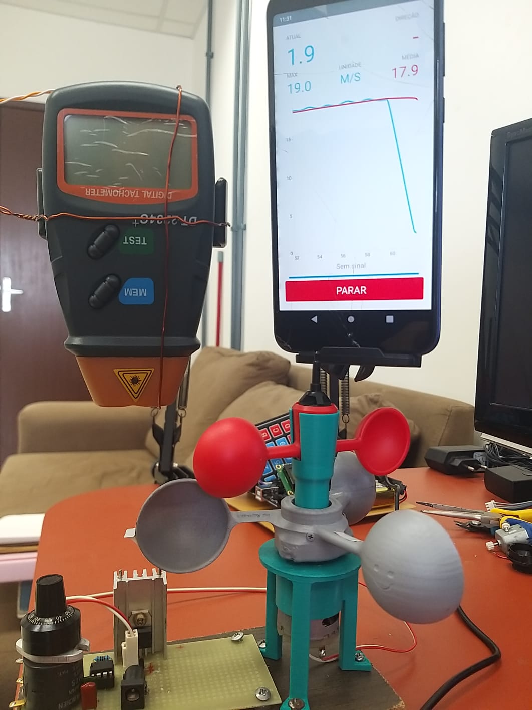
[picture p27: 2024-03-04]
Anemometro/Imagens da Calibracao/Calibracao com anemometro vaavud e tacometro.jpeg

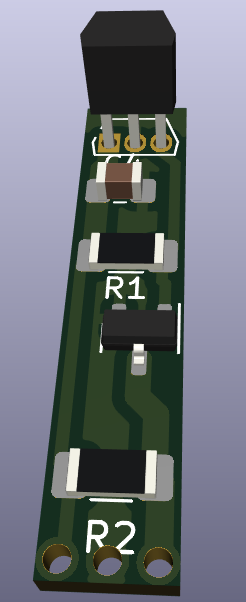
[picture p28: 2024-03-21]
Anemometro/Imagens da Calibracao/sensor magnético PCB.png

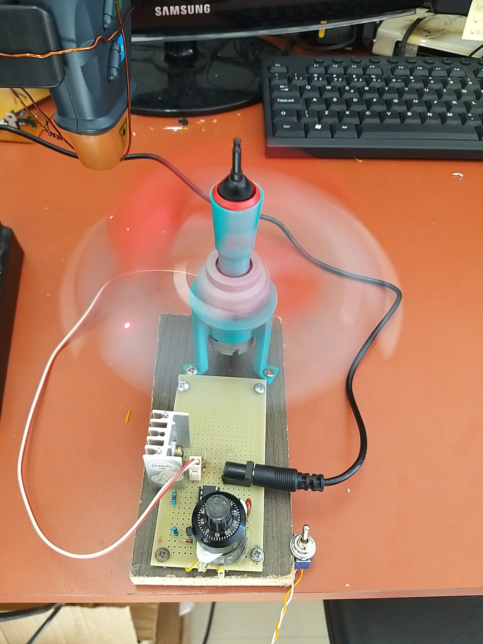
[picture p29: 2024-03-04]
Anemometro/Imagens da Calibracao/Calibracao com anemometro vaavud s.jpeg

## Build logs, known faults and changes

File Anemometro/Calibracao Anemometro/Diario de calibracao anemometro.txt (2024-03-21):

------------------Dia 15/12/2023------------------

Para melhor resposta do tacômetro, deixei mais firme a fita reflexiva

Reorganizei o código de tratamento dos dados para análise de frequencia angular e velocidade

Para cada velocidade do vaavud, será coletado cinco amostras de RPM e feita média. A amostra será constante e em seguida que aparecer no visor, será esse o valor usado.

Amostras 
    Resistencia: 7k a 8k
    
    resistencia = [7, 7, 7, 7.3, 7.3, 7.3, 7.6, 7.6, 7.8, 8]
    RPM:  [952.0200000000001, 921.1200000000001, 917.72, 935.1, 935.36, 929.3, 919.4200000000001, 939.9800000000001, 948.18, 951.5200000000001]
    m/s: [17.2, 16.7, 16.6, 17.0, 17.1, 16.8, 16.7, 17.0, 17.1, 17.3]

------------------Dia 18/12/2023------------------
Amostras 
    Resistencia: 8k a 9k
    RPM:  [981.54, 990.9399999999999, 983.32, 1003.22, 1003.46, 1007.1600000000001, 1013.9400000000002, 1014.3, 1001.24, 995.0600000000001]
    m/s: [17.8, 17.9, 18.0, 18.1, 18.3, 18.3, 18.4, 18.5, 18.3, 18.2]
    Resistencia: [8.0, 8.1, 8.2, 8.3, 8.4, 8.5, 8.7, 8.8, 8.9, 9.0]

Amostras 
    Resistencia: 9k a 10k
    RPM =  [1059.9199999999998, 1035.78, 1042.3799999999999, 1029.36, 1025.7800000000002, 1033.16, 1030.1599999999999, 1027.4599999999998, 1026.1, 1025.08]
    m/s = [19.4, 18.8, 18.8, 18.6, 18.7, 18.8, 18.9, 18.6, 18.7, 18.5]
    Resistencia = [9.0, 9.1, 9.2, 9.3, 9.4, 9.5, 9.7, 9.8, 9.9, 10.0]

Amostras 
    Resistencia: 5k a 6k
    RPM =  [788.4, 798.28, 810.0, 821.6, 830.6199999999999, 840.26, 846.0600000000001, 853.8799999999999, 862.1600000000001, 874.4]
    m/s = [14.3, 14.5, 14.6, 14.9, 15.2, 15.0, 15.3, 15.5, 15.7, 15.9]
    Resistencia = [5.0, 5.1, 5.2, 5.3, 5.4, 5.5, 5.6, 5.7, 5.8, 6.0]

Amostras 
    Resistencia: 4k a 5k 
    RPM =  [746.84, 713.3199999999999, 729.74, 738.64, 750.3, 760.7, 768.8199999999999, 798.8199999999999, 798.1600000000001, 789.8]
    m/s = [12.7, 13.0, 13.2, 13.4, 13.6, 13.8, 14.0, 14.5, 14.4, 14.5]
    Resistencia = [4.0, 4.2, 4.3, 4.4, 4.5, 4.6, 4.7, 5.0, 5.0, 5.0]

Amostras 
    Resistencia: 5k a 6k
    RPM =  [791.26, 789.8399999999999, 808.6800000000001, 810.2800000000001, 835.3799999999999, 837.9199999999998, 851.36, 847.8399999999999, 874.82, 873.7]
    m/s = [14.4, 14.4, 14.6, 14.8, 15.3, 15.2, 15.5, 15.5, 15.9, 15.8]
    Resistencia = [5.0, 5.0, 5.2, 5.2, 5.5, 5.5, 5.7, 5.7, 6.0, 6.0]

Amostras 
    Resistencia: 3k a 4k
    RPM =  [581.84, 580.3199999999999, 578.5, 577.58, 582.7, 697.6800000000001, 700.88, 697.02, 695.74, 695.1600000000001]
    m/s = [10.6, 10.5, 10.6, 10.5, 10.6, 12.7, 12.7, 12.7, 12.6, 12.7]
    Resistencia = [3.0, 3.0, 3.0, 3.0, 3.0, 4.0, 4.0, 4.0, 4.0, 4.0]

Amostras 
    Resistencia: 1k
    RPM =  [260.7, 255.34, 254.95999999999998, 254.28000000000003, 251.82, 251.88000000000002, 249.68, 248.14000000000001, 248.76, 244.61999999999998]
    m/s = [5.0, 4.8, 4.8, 4.8, 4.8, 4.8, 4.7, 4.8, 4.6, 4.5]
    Resistencia = [1.0, 1.0, 1.0, 1.0, 1.0, 1.0, 1.0, 1.0, 1.0, 1.0]

Amostras 
    Resistencia: 1.5k
    RPM =  [344.42, 342.8, 343.98, 341.18, 342.0, 343.97999999999996, 338.25999999999993, 337.49999999999994, 334.0, 336.65999999999997]
    m/s = [6.4, 6.4, 6.4, 6.4, 6.4, 6.4, 6.3, 6.3, 6.3, 6.2]
    Resistencia = [1.5, 1.5, 1.5, 1.5, 1.5, 1.5, 1.5, 1.5, 1.5, 1.5]

Amostras 
    Resistencia: 2k
    RPM =  [432.1, 433.62, 434.1, 435.08000000000004, 436.64, 437.71999999999997, 440.73999999999995, 436.28000000000003, 440.23999999999995, 437.52]
    m/s = [8.0, 7.9, 8.0, 8.0, 8.0, 8.0, 8.0, 8.1, 8.1, 8.1]
    Resistencia = [2.0, 2.0, 2.0, 2.0, 2.0, 2.0, 2.0, 2.0, 2.0, 2.0]

Amostras 
    Resistencia: 2.5k
    RPM =  [500.76000000000005, 496.78000000000003, 500.84000000000003, 501.12, 501.6, 504.08000000000004, 502.78000000000003, 506.0, 506.08000000000004, 507.41999999999996]
    M_S = [9.3, 9.2, 9.2, 9.2, 9.2, 9.2, 9.2, 9.2, 9.3, 9.3]
    Resistencia = [2.5, 2.5, 2.5, 2.5, 2.5, 2.5, 2.5, 2.5, 2.5, 2.5]

Amostras 
    Resistencia: 3k
    RPM =  [569.62, 571.26, 576.4999999999999, 572.8199999999999, 573.4799999999999, 574.86, 573.8399999999999, 571.52, 573.54, 575.9]
    M_S = [10.4, 10.4, 10.4, 10.4, 10.5, 10.5, 10.4, 10.5, 10.5, 10.4]
    Resistencia = [3.0, 3.0, 3.0, 3.0, 3.0, 3.0, 3.0, 3.0, 3.0, 3.0]

Amostras 
    Resistencia: 4k
    RPM =  [692.86, 696.5600000000001, 689.28, 692.3199999999999, 692.6200000000001, 694.6800000000001, 695.04, 694.58, 694.7599999999999, 692.66]
    M_S = [12.6, 12.5, 12.6, 12.6, 12.5, 12.6, 12.6, 12.5, 12.6, 12.6]
    Resistencia = [4.0, 4.0, 4.0, 4.0, 4.0, 4.0, 4.0, 4.0, 4.0, 4.0]

------------------Dia 19/12/2023------------------
Amostras 
    Resistencia: 4.5k
    RPM =  [728.32, 724.5200000000001, 728.4, 730.1600000000001, 726.7800000000001, 727.7, 727.36, 727.4000000000001, 728.2, 726.3399999999999]
    M_S = [13.2, 13.2, 13.2, 13.2, 13.2, 13.2, 13.2, 13.2, 13.1, 13.2]
    Resistencia = [4.5, 4.5, 4.5, 4.5, 4.5, 4.5, 4.5, 4.5, 4.5, 4.5]

Amostras 
    Resistencia: 3.5k
    rpm =  [616.96, 615.8800000000001, 618.5600000000001, 616.84, 616.76, 617.1800000000001, 615.16, 614.88, 615.7, 612.36]
    m_s = [11.1, 11.2, 11.2, 11.2, 11.2, 11.3, 11.3, 11.2, 11.1, 11.2]
    Resistencia = [3.5, 3.5, 3.5, 3.5, 3.5, 3.5, 3.5, 3.5, 3.5, 3.5]

Amostras 
    Resistencia: 5k
    rpm =  [780.36, 774.4200000000001, 779.1600000000001, 779.3799999999999, 779.6600000000001, 778.8799999999999, 777.9399999999999, 777.98, 777.2199999999999, 779.86]
    m_s = [14.0, 14.2, 14.1, 14.2, 14.1, 14.1, 14.2, 14.2, 14.0, 14.1]
    Resistencia = [5.0, 5.0, 5.0, 5.0, 5.0, 5.0, 5.0, 5.0, 5.0, 5.0]

Resultado para 120 amostras
Tamanho da amostra:  150
    w minimo: 25.60356    m/s minimo:  4.5
    w maximo: 110.9382933333333    m/s máximo:  19.4 

    Media de freq. angular:         71.95933813333333
    Desvio padrao de freq. angular: 23.613961587977695 

    Equação da reta da regressão linear
    [0.17117843]x + 0.19744649996588137
    Equação da reta da regressão linear
    [9.44670451]x + 29.20985132

Total dos dados:
    rpm = [981.54, 990.9399999999999, 983.32, 1003.22, 1003.46, 1007.1600000000001, 1013.9400000000002, 1014.3, 1001.24, 995.0600000000001,
            952.0200000000001, 921.1200000000001, 917.72, 935.1, 935.36, 929.3, 919.4200000000001, 939.9800000000001, 948.18, 951.5200000000001,
            788.4, 798.28, 810.0, 821.6, 830.6199999999999, 840.26, 846.0600000000001, 853.8799999999999, 862.1600000000001, 874.4,
            791.26, 789.8399999999999, 808.6800000000001, 810.2800000000001, 835.3799999999999, 837.9199999999998, 851.36, 847.8399999999999, 874.82, 873.7,
            260.7, 255.34, 254.95999999999998, 254.28000000000003, 251.82, 251.88000000000002, 249.68, 248.14000000000001, 248.76, 244.61999999999998,
            432.1, 433.62, 434.1, 435.08000000000004, 436.64, 437.71999999999997, 440.73999999999995, 436.28000000000003, 440.23999999999995, 437.52,
            344.42, 342.8, 343.98, 341.18, 342.0, 343.97999999999996, 338.25999999999993, 337.49999999999994, 334.0, 336.65999999999997,
            500.76000000000005, 496.78000000000003, 500.84000000000003, 501.12, 501.6, 504.08000000000004, 502.78000000000003, 506.0, 506.08000000000004, 507.41999999999996,
            569.62, 571.26, 576.4999999999999, 572.8199999999999, 573.4799999999999, 574.86, 573.8399999999999, 571.52, 573.54, 575.9,
            692.86, 696.5600000000001, 689.28, 692.3199999999999, 692.6200000000001, 694.6800000000001, 695.04, 694.58, 694.7599999999999, 692.66,
            728.32, 724.5200000000001, 728.4, 730.1600000000001, 726.7800000000001, 727.7, 727.36, 727.4000000000001, 728.2, 726.3399999999999,
            1059.9199999999998, 1035.78, 1042.3799999999999, 1029.36, 1025.7800000000002, 1033.16, 1030.1599999999999, 1027.4599999999998, 1026.1, 1025.08,
            746.84, 713.3199999999999, 729.74, 738.64, 750.3, 760.7, 768.8199999999999, 798.8199999999999, 798.1600000000001, 789.8,
            616.96, 615.8800000000001, 618.5600000000001, 616.84, 616.76, 617.1800000000001, 615.16, 614.88, 615.7, 612.36,
            780.36, 774.4200000000001, 779.1600000000001, 779.3799999999999, 779.6600000000001, 778.8799999999999, 777.9399999999999, 777.98, 777.2199999999999, 779.86]

    m_s = [17.8, 17.9, 18.0, 18.1, 18.3, 18.3, 18.4, 18.5, 18.3, 18.2, 
           17.2, 16.7, 16.6, 17.0, 17.1, 16.8, 16.7, 17.0, 17.1, 17.3,
           14.3, 14.5, 14.6, 14.9, 15.2, 15.0, 15.3, 15.5, 15.7, 15.9,
            14.4, 14.4, 14.6, 14.8, 15.3, 15.2, 15.5, 15.5, 15.9, 15.8,
            5.0, 4.8, 4.8, 4.8, 4.8, 4.8, 4.7, 4.8, 4.6, 4.5,
            8.0, 7.9, 8.0, 8.0, 8.0, 8.0, 8.0, 8.1, 8.1, 8.1,
            6.4, 6.4, 6.4, 6.4, 6.4, 6.4, 6.3, 6.3, 6.3, 6.2,
            9.3, 9.2, 9.2, 9.2, 9.2, 9.2, 9.2, 9.2, 9.3, 9.3,
            10.4, 10.4, 10.4, 10.4, 10.5, 10.5, 10.4, 10.5, 10.5, 10.4,
            12.6, 12.5, 12.6, 12.6, 12.5, 12.6, 12.6, 12.5, 12.6, 12.6,
            13.2, 13.2, 13.2, 13.2, 13.2, 13.2, 13.2, 13.2, 13.1, 13.2,
            19.4, 18.8, 18.8, 18.6, 18.7, 18.8, 18.9, 18.6, 18.7, 18.5,
            12.7, 13.0, 13.2, 13.4, 13.6, 13.8, 14.0, 14.5, 14.4, 14.5,
            11.1, 11.2, 11.2, 11.2, 11.2, 11.3, 11.3, 11.2, 11.1, 11.2,
            14.0, 14.2, 14.1, 14.2, 14.1, 14.1, 14.2, 14.2, 14.0, 14.1]

    resistencia = [8.0, 8.1, 8.2, 8.3, 8.4, 8.5, 8.7, 8.8, 8.9, 9.0,
            7, 7, 7, 7.3, 7.3, 7.3, 7.6, 7.6, 7.8, 8,        
            5.0, 5.1, 5.2, 5.3, 5.4, 5.5, 5.6, 5.7, 5.8, 6.0,
            5.0, 5.0, 5.2, 5.2, 5.5, 5.5, 5.7, 5.7, 6.0, 6.0,
            1.0, 1.0, 1.0, 1.0, 1.0, 1.0, 1.0, 1.0, 1.0, 1.0,
            2.0, 2.0, 2.0, 2.0, 2.0, 2.0, 2.0, 2.0, 2.0, 2.0,
            1.5, 1.5, 1.5, 1.5, 1.5, 1.5, 1.5, 1.5, 1.5, 1.5,
            2.5, 2.5, 2.5, 2.5, 2.5, 2.5, 2.5, 2.5, 2.5, 2.5,
            3.0, 3.0, 3.0, 3.0, 3.0, 3.0, 3.0, 3.0, 3.0, 3.0,
            4.0, 4.0, 4.0, 4.0, 4.0, 4.0, 4.0, 4.0, 4.0, 4.0,
            4.5, 4.5, 4.5, 4.5, 4.5, 4.5, 4.5, 4.5, 4.5, 4.5,
            9.0, 9.1, 9.2, 9.3, 9.4, 9.5, 9.7, 9.8, 9.9, 10.0,
            4.0, 4.2, 4.3, 4.4, 4.5, 4.6, 4.7, 5.0, 5.0, 5.0,
            3.5, 3.5, 3.5, 3.5, 3.5, 3.5, 3.5, 3.5, 3.5, 3.5,
            5.0, 5.0, 5.0, 5.0, 5.0, 5.0, 5.0, 5.0, 5.0, 5.0]

------------------Dia 15/01/2024------------------

Após alguns dias testando e analisando o comportamento de leitura do sensor Hall ao anemômetro, estamos chegando perto da calibração
Ainda há algumas diferenças nas leituras da velocidade, no espaço que estamos usando de 0m/s á 21m/s, os valores mais extremos estão bem próximos, já os valores entre 10m/s e 17m/s variam até 2m/s, algumas vezes os valores são bem, similares.

Código sendo usado:

    const byte PulsesPerRevolution = 3; 
    const unsigned long ZeroTimeout = 500000; 
    // Calibration for smoothing RPM:
    const byte numReadings = 15;  // Number of samples for smoothing. The higher, the more smoothing, but it's going to
                                 // react slower to changes. 1 = no smoothing. Default: 2.

    volatile unsigned long LastTimeWeMeasured;  // Stores the last time we measured a pulse so we can calculate the period.
    volatile unsigned long PeriodBetweenPulses = ZeroTimeout+1000;  // Stores the period between pulses in microseconds.
                           // It has a big number so it doesn't start with 0 which would be interpreted as a high frequency.
    volatile unsigned long PeriodAverage = ZeroTimeout+1000;  // Stores the period between pulses in microseconds in total, if we are taking multiple pulses.
                           // It has a big number so it doesn't start with 0 which would be interpreted as a high frequency.
    unsigned long FrequencyRaw;  // Calculated frequency, based on the period. This has a lot of extra decimals without the decimal point.
    unsigned long FrequencyReal;  // Frequency without decimals.
    unsigned long RPM;  // Raw RPM without any processing.
    unsigned int PulseCounter = 1;  // Counts the amount of pulse readings we took so we can average multiple pulses before calculating the period.

    unsigned long PeriodSum; // Stores the summation of all the periods to do the average.

    unsigned long LastTimeCycleMeasure = LastTimeWeMeasured;  // Stores the last time we measure a pulse in that cycle.
                                        // We need a variable with a value that is not going to be affected by the interrupt
                                        // because we are going to do math and functions that are going to mess up if the values
                                        // changes in the middle of the cycle.
    unsigned long CurrentMicros = micros();  // Stores the micros in that cycle.
                                             // We need a variable with a value that is not going to be affected by the interrupt
                                             // because we are going to do math and functions that are going to mess up if the values
                                             // changes in the middle of the cycle.

    // We get the RPM by measuring the time between 2 or more pulses so the following will set how many pulses to
    // take before calculating the RPM. 1 would be the minimum giving a result every pulse, which would feel very responsive
    // even at very low speeds but also is going to be less accurate at higher speeds.
    // With a value around 10 you will get a very accurate result at high speeds, but readings at lower speeds are going to be
    // farther from eachother making it less "real time" at those speeds.
    // There's a function that will set the value depending on the speed so this is done automatically.
    unsigned int AmountOfReadings = 1;

    unsigned int ZeroDebouncingExtra;  // Stores the extra value added to the ZeroTimeout to debounce it.
                                       // The ZeroTimeout needs debouncing so when the value is close to the threshold it
                                       // doesn't jump from 0 to the value. This extra value changes the threshold a little
                                       // when we show a 0.

    // Variables for smoothing tachometer:
    unsigned long readings[numReadings];  // The input.
    unsigned long readIndex;  // The index of the current reading.
    unsigned long total;  // The running total.
    unsigned long average;  // The RPM value after applying the smoothing.

    // Freqeuncia angular
    unsigned long FrequenciaAng;
    float calibracao = (1.53)*2*3.14/60;
    // Velocdade inicial
    float Velocidade;

    // OLED 0.96" Display:
    #include <Adafruit_GFX.h>  // Include core graphics library for the display.
    #include <Adafruit_SSD1306.h>  // Include Adafruit_SSD1306 library to drive the display.Adafruit_SSD1306 display(128, 64);  // Create display.
    #include <Fonts/FreeMonoBold18pt7b.h>  // Add a custom font.
    //
    #define SCREEN_WIDTH 128
    #define SCREEN_HEIGHT 64
    Adafruit_SSD1306 display(SCREEN_WIDTH, SCREEN_HEIGHT, &Wire, -1);

    void setup()  // Start of setup:
    {

      Serial.begin(9600);  // Begin serial communication.
      attachInterrupt(digitalPinToInterrupt(2), Pulse_Event, RISING);  // Enable interruption pin 2 when going from LOW to HIGH.

      delay(1000);

      // OLED 0.96" Display:
      display.begin(SSD1306_SWITCHCAPVCC, 0x3C);  // Initialize display with the I2C address of 0x3C.
      display.clearDisplay();  // Clear the buffer.
      display.setTextColor(WHITE);  // Set color of the text to white.
      display.setRotation(0);  // Set orientation. Goes from 0, 1, 2 or 3.
      display.setTextWrap(false);  // By default, long lines of text are set to automatically “wrap” back to the leftmost column.
                                   // To override this behavior (so text will run off the right side of the display - useful for
                                   // scrolling marquee effects), use setTextWrap(false). The normal wrapping behavior is restored
                                   // with setTextWrap(true).
      display.dim(0);  // Set brightness (0 is maximum and 1 is a little dim).
      
    }

    void loop()  // Start of loop:
    {
      LastTimeCycleMeasure = LastTimeWeMeasured;  // Store the LastTimeWeMeasured in a variable.
      CurrentMicros = micros();  // Store the micros() in a variable.

      if(CurrentMicros < LastTimeCycleMeasure)
      {
        LastTimeCycleMeasure = CurrentMicros;
      }

      // Calculate the frequency:
      FrequencyRaw = 10000000000 / PeriodAverage;  // Calculate the frequency using the period between pulses.

      // Detect if pulses stopped or frequency is too low, so we can show 0 Frequency:
      if(PeriodBetweenPulses > ZeroTimeout - ZeroDebouncingExtra || CurrentMicros - LastTimeCycleMeasure > ZeroTimeout - ZeroDebouncingExtra)
      {  // If the pulses are too far apart that we reached the timeout for zero:
        FrequencyRaw = 0;  // Set frequency as 0.
        ZeroDebouncingExtra = 2000;  // Change the threshold a little so it doesn't bounce.
      }
      else
      {
        ZeroDebouncingExtra = 0;  // Reset the threshold to the normal value so it doesn't bounce.
      }

      FrequencyReal = FrequencyRaw / 10000;  // Get frequency without decimals.
                                            
      // Calculate the RPM:
      RPM = FrequencyRaw / PulsesPerRevolution * 60;  // Frequency divided by amount of pulses per revolution multiply by
                                                      // 60 seconds to get minutes.
      RPM = RPM / 10000;  // Remove the decimals.

      // Smoothing RPM:
      total = total - readings[readIndex];  // Advance to the next position in the array.
      readings[readIndex] = RPM;  // Takes the value that we are going to smooth.
      total = total + readings[readIndex];  // Add the reading to the total.
      readIndex = readIndex + 1;  // Advance to the next position in the array.

      if (readIndex >= numReadings)  // If we're at the end of the array:
      {
        readIndex = 0;  // Reset array index.
      }
      
      // Calculate the average:
      average = total / numReadings;  // The average value it's the smoothed result.

      FrequenciaAng = calibracao * average;
      Velocidade = 0.17128525*FrequenciaAng + 0.2037372;

      Serial.print("FreqAng: ");
      Serial.print(FrequenciaAng);
      Serial.print("\tVelocidade: ");
      Serial.println(Velocidade);

      // OLED 0.96" Display:
      // Convert variable into a string, so we can change the text alignment to the right:
      // It can be also used to add or remove decimal numbers.
       char string[10];  // Create a character array of 10 characters
      // Convert float to a string:
      dtostrf(Velocidade, 6, 0, string);  // (<variable>,<amount of digits we are going to use>,<amount of decimal digits>,<string name>)

      display.clearDisplay();  // Clear the display so we can refresh.
      display.setFont(&FreeMonoBold18pt7b);  // Set a custom font.
      display.setTextSize(0);  // Set text size. We are using a custom font so you should always use the text size of 0.
      display.setCursor(0, 25);  // (x,y).
      display.println("Vel:");  // Text or value to print.

      // Print variable with right alignment:
      display.setCursor(0, 60);  // (x,y).
      display.println(string);  // Text or value to print.

      // Print a comma for the thousands separator:
      if(average > 999)  // If value is above 999:
      {
        // Draw line (to show a comma):
        display.drawLine(63, 60, 61, 65, WHITE);  // Draw line (x0,y0,x1,y1,color).
      }

      display.display();  // Print everything we set previously.
      delay(10);
    }  // End of loop.

    void Pulse_Event()  // The interrupt runs this to calculate the period between pulses:
    {

      PeriodBetweenPulses = micros() - LastTimeWeMeasured;  

      LastTimeWeMeasured = micros();  // Stores the current micros so the next time we have a pulse we would have something to compare with.

      if(PulseCounter >= AmountOfReadings)  // If counter for amount of readings reach the set limit:
      {
        PeriodAverage = PeriodSum / AmountOfReadings;  // Calculate the final period dividing the sum of all readings by the
                                                       // amount of readings to get the average.
        PulseCounter = 1;  // Reset the counter to start over. The reset value is 1 because its the minimum setting allowed (1 reading).
        PeriodSum = PeriodBetweenPulses;  // Reset PeriodSum to start a new averaging operation.

        int RemapedAmountOfReadings = map(PeriodBetweenPulses, 40000, 5000, 1, 10);  // Remap the period range to the reading range.
        
        RemapedAmountOfReadings = constrain(RemapedAmountOfReadings, 1, 10);  // Constrain the value so it doesn't go below or above the limits.
        AmountOfReadings = RemapedAmountOfReadings;  // Set amount of readings as the remaped value.
      }
      else
      {
        PulseCounter++;  // Increase the counter for amount of readings by 1.
        PeriodSum = PeriodSum + PeriodBetweenPulses;  // Add the periods so later we can average.
      }

    }

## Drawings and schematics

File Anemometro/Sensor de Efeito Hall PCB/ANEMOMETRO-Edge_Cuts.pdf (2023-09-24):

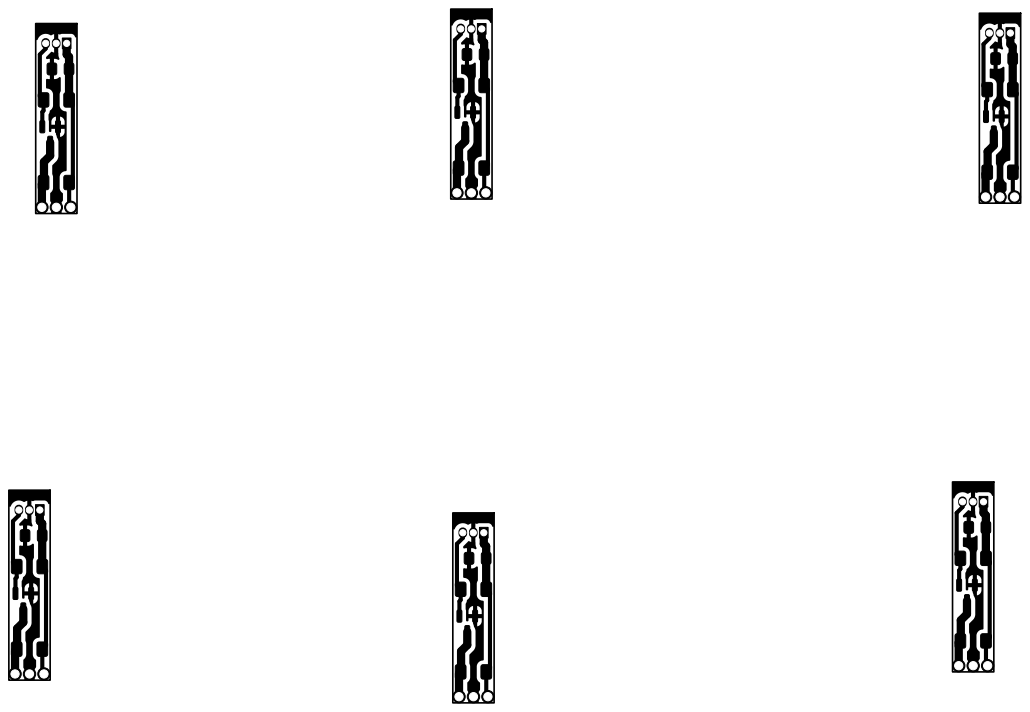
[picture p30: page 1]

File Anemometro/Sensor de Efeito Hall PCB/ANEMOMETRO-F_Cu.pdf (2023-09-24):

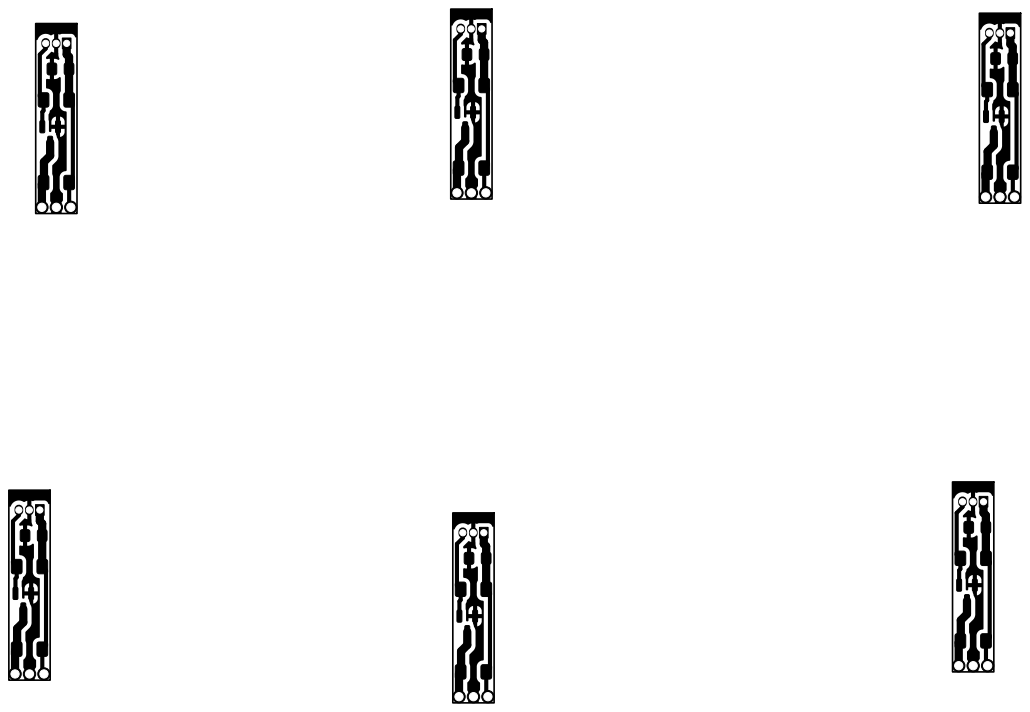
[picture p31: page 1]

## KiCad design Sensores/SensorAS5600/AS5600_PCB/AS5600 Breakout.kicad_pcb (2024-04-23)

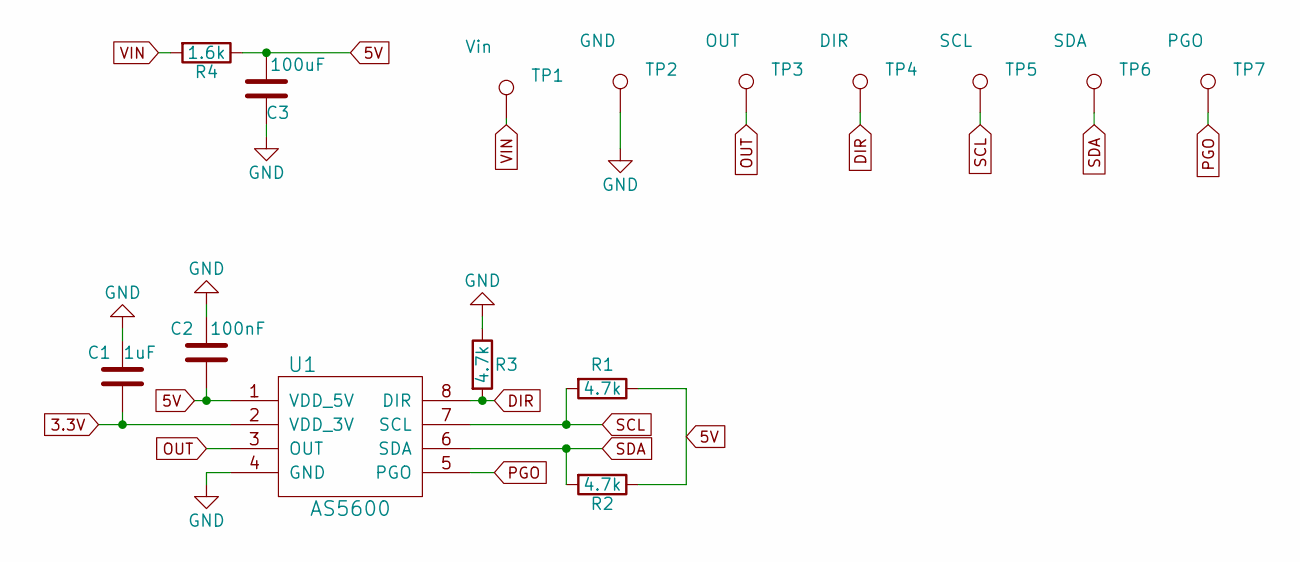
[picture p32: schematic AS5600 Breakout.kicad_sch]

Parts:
C1: 1uF; C_0805
C2: 100nF; C_0805
C3: 100uF; C_1210
R1, R2, R3: 4.7k; R_0805
R4: 1.6k; R_0805
TP1: Vin; TestPoint_Pad_D1.0mm
TP2: GND; TestPoint_Pad_D1.0mm
TP3: OUT; TestPoint_Pad_D1.0mm
TP4: DIR; TestPoint_Pad_D1.0mm
TP5: SCL; TestPoint_Pad_D1.0mm
TP6: SDA; TestPoint_Pad_D1.0mm
TP7: PGO; TestPoint_Pad_D1.0mm
U1: AS5600; SOIC-8-N; Manufacturer Part Number AS5600-ASOM

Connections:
3.3V: C1.2, U1.2 (VDD_3V)
5V: C2.1, C3.2, R1.1, R2.1, R4.1, U1.1 (VDD_5V)
DIR: R3.2, TP4.1, U1.8 (DIR)
GND: C1.1, C2.2, C3.1, R3.1, TP2.1, U1.4 (GND)
OUT: TP3.1, U1.3 (OUT)
PGO: TP7.1, U1.5 (PGO)
SCL: R1.2, TP5.1, U1.7 (SCL)
SDA: R2.2, TP6.1, U1.6 (SDA)
VIN: R4.2, TP1.1

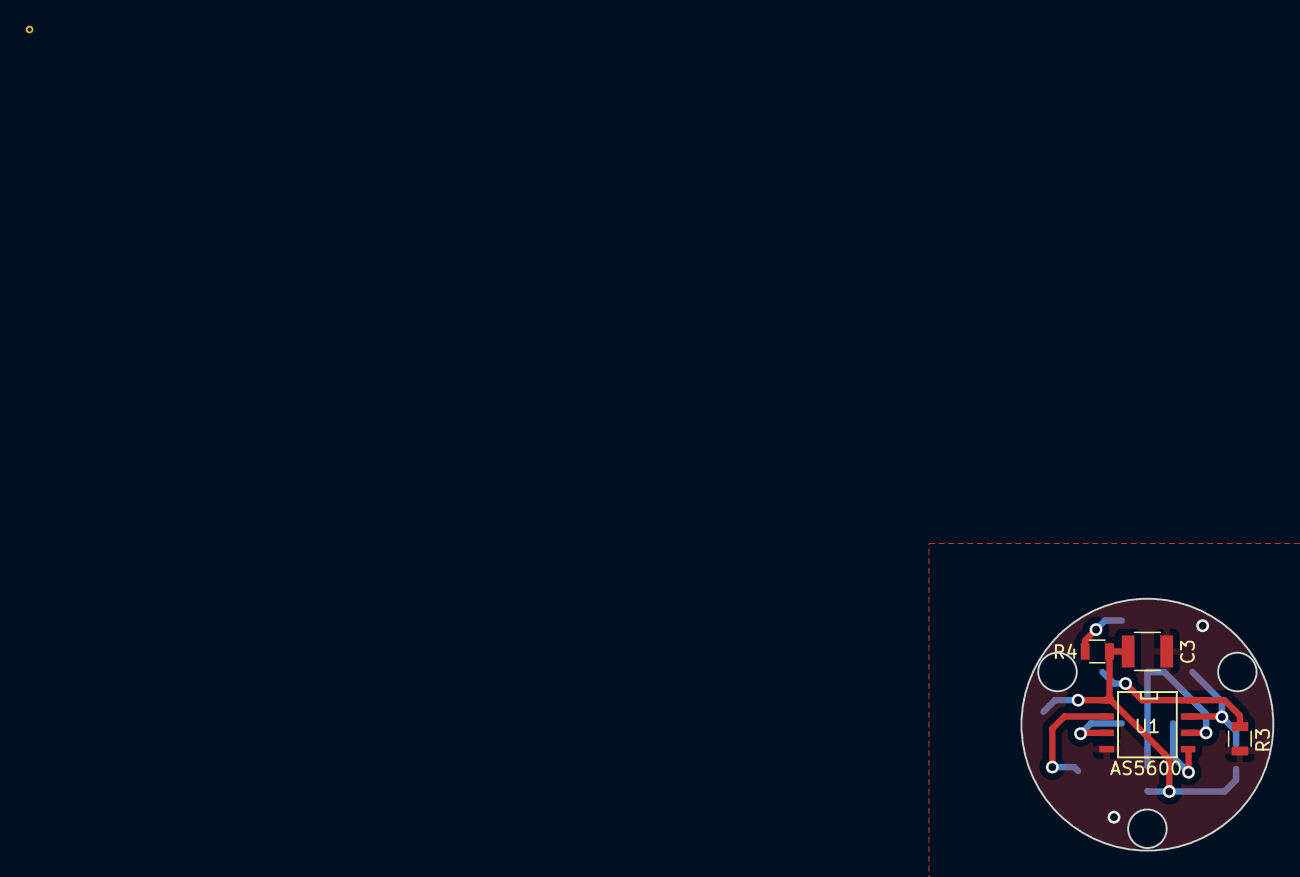
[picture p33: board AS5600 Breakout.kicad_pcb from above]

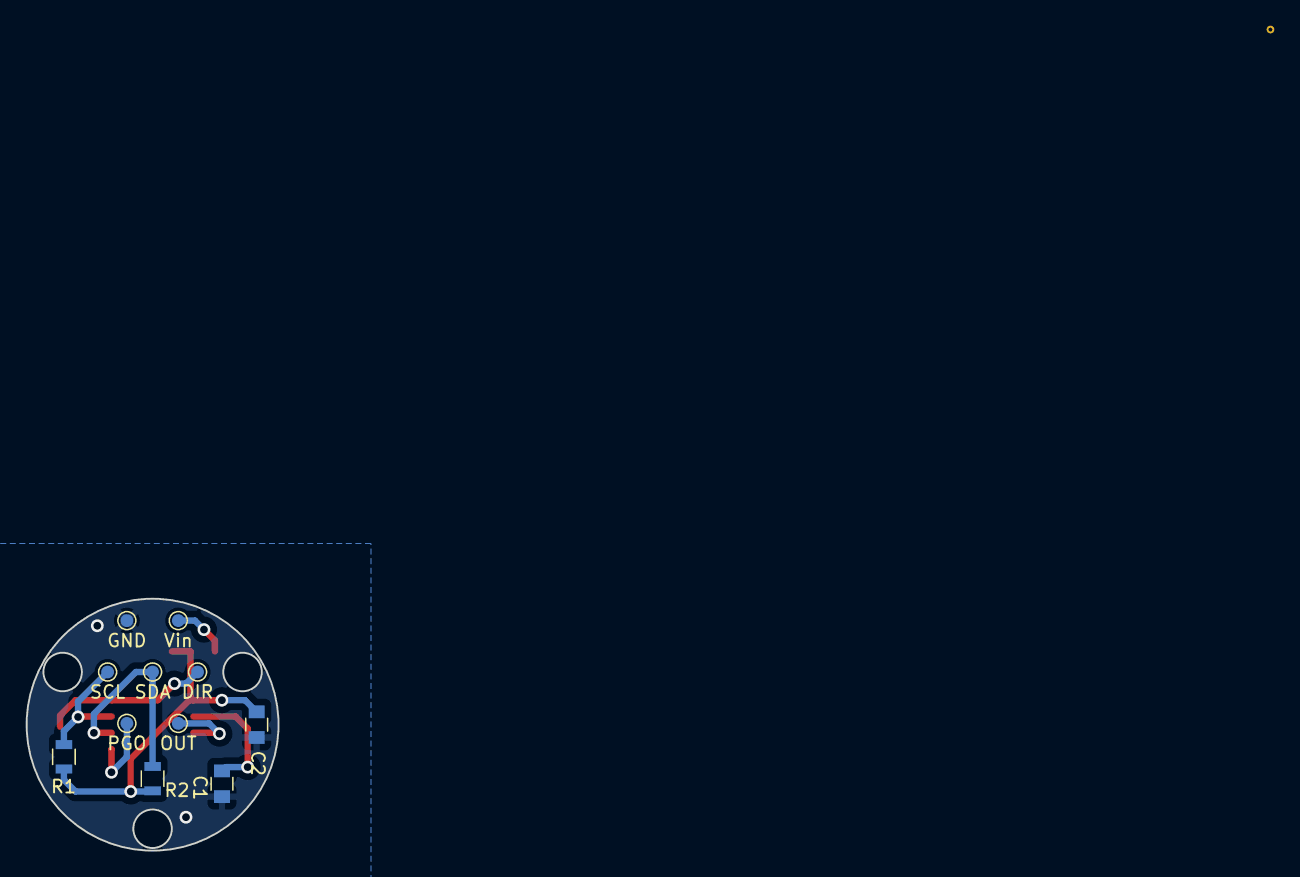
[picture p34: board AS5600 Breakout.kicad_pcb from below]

Board: 2 copper layers, 19.6 x 19.6 mm, 15 parts (11 on the bottom side), 9 nets.

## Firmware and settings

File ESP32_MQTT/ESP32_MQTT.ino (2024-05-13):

/*
  Receiving data from another station through LoRa module and sending to NodeRed
*/
#include <WiFi.h>
#include <PubSubClient.h>
#include <Wire.h>
#include <Adafruit_GFX.h>
#include <Adafruit_SSD1306.h>
#include "EBYTE.h"

#define PIN_RX 16  // Serial2 RX (connect this to the EBYTE Tx pin)
#define PIN_TX 17  // Serial2 TX pin (connect this to the EBYTE Rx pin)

#define PIN_M0 4   // D4 on the board (possibly pin 24)
#define PIN_M1 19  // D2 on the board (possibly called pin 22)
#define PIN_AX 18  // D15 on the board (possibly called pin 21)

#define SCREEN_WIDTH 128  // Largura do display em pixels
#define SCREEN_HEIGHT 64  // Altura do display em pixels

// ====================================================================================================================================
// --- Oled configuration ---
Adafruit_SSD1306 display(SCREEN_WIDTH, SCREEN_HEIGHT, &Wire, -1);

// ====================================================================================================================================
// --- Struct with station data
struct DATA {
  float Temp;
  float Humid;
  float Press;
  float Altitude;
  float Speed;
  float Direction;
};

int Chan;
DATA StationA;
DATA StationB;
unsigned long Last;
unsigned long intervalSearching = 8000; //time to start to serching data

// create the transceiver object, passing in the serial and pins
EBYTE Transceiver(&Serial2, PIN_M0, PIN_M1, PIN_AX);
// ====================================================================================================================================
// --- Conect wifi ---
// const char* ssid     = "Sala_J13";
// const char* password = "salaj132023";
const char* ssid = "VETORIAL_11";
const char* password = "07072022";
// const char* ssid = "A9";
// const char* password = "12345678";

const char* mqtt_server = "test.mosquitto.org";

WiFiClient espClient;
PubSubClient client(espClient);
long lastMsg = 0;
char msg[50];
int value = 0;

//Conecta-se com o Wifi
void setup_wifi(unsigned long Last) {
  unsigned long interval = 6000;  //interval to return from loop
  delay(10);
  // We start by connecting to a WiFi network
  Serial.println();
  Serial.print("Connecting to ");
  Serial.println(ssid);

  WiFi.begin(ssid, password);

  while (WiFi.status() != WL_CONNECTED) {
    delay(500);
    Serial.print(".");
    if ((millis() - Last) >= interval) {
      Serial.println("Failure to connect to Wifi :(");
      delay(500);
      return;
    }
  }
  randomSeed(micros());

  Serial.println("");
  Serial.println("WiFi connected");
  Serial.println("IP address: ");
  Serial.println(WiFi.localIP());
}


//Esp recebe informações
void callback(char* topic, byte* payload, unsigned int length) {
  Serial.print("Message arrived [");
  Serial.print(topic);
  Serial.print("] ");
  for (int i = 0; i < length; i++) {
    Serial.print((char)payload[i]);
  }
  Serial.println();
}

//Conecta-se com o MQTT
void reconnect(unsigned long Last) {
  unsigned long interval = 6000;  //interval to return from loop
  if (WiFi.status() != WL_CONNECTED){
    Serial.println("Connecting to Wifi");
  }
  while (WiFi.status() != WL_CONNECTED) {
    delay(500);
    Serial.print(".");
    if ((millis() - Last) >= interval) {
      Serial.println("Failure to connect to wifi :(");
      delay(500);
      return;
    }
  }
  // Loop until we're reconnected
  while (!client.connected()) {
    Serial.print("Attempting MQTT connection...");
    // Create a random client ID
    String clientId = "espClient";
    clientId += String(random(0xffff), HEX);
    // Attempt to connect
    if (client.connect(clientId.c_str())) {
      Serial.println("connected");

      client.subscribe("estacao");
    } else {
      Serial.print("failed, rc=");
      Serial.print(client.state());
      Serial.println(" try again in 5 seconds");
      // Wait 5 seconds before retrying

      if ((millis() - Last) >= interval) {
        Serial.println("Failure to connect :(");
        delay(500);
        return;
      }
      delay(5000);
    }
  }
}

void displayFunction(float temp, float humid, float speed, float altitude, float press,float direction) {
  display.clearDisplay();
  display.setCursor(45, 0);
  display.setTextColor(SSD1306_WHITE, SSD1306_BLACK);
  display.print("MASTER");

  display.setTextColor(SSD1306_WHITE);
  display.setCursor(0, 20);
  display.print("T:"); display.print(temp); display.print("C");

  display.setCursor(70, 20);
  display.print("H: "); display.print(humid); display.println("%");

  display.setCursor(0, 35);
  display.print("S:"); display.print(speed); display.print("m/s");

  display.setCursor(70, 35);
  display.print("A:"); display.print(altitude); display.println("m");

  display.setCursor(0, 50);
  display.print("P:"); display.print(press); display.println("Pa");

  display.setCursor(70, 50);
  display.print("D:"); display.print(direction); display.println("º");
  
  display.display();
}

void displaySearchingData(){
  display.clearDisplay();
  display.setCursor(45, 0);
  display.setTextColor(SSD1306_WHITE, SSD1306_BLACK);
  display.print("MASTER");

  display.setCursor(10, 20);
  display.println("Searching for         data...");
  display.display();
  delay(1500);
  display.clearDisplay();
}

void setup() {
  Serial.begin(9600);

  Last = millis();
  setup_wifi(Last);

  client.setServer(mqtt_server, 1883);
  client.setCallback(callback);

  Serial2.begin(9600);
  Serial.println("Starting Reader");

  // this init will set the pinModes for you
  Transceiver.init();

  // all these calls are optional but shown to give examples of what you can do

  // Serial.println(Transceiver.GetAirDataRate());
  // Serial.println(Transceiver.GetChannel());
  Transceiver.SetAddressH(0x01);
  Transceiver.SetAddressL(0x01);
  Chan = 23;
  Transceiver.SetChannel(Chan);
  // save the parameters to the unit,
  // Transceiver.SetPullupMode(1);
  // Transceiver.SaveParameters(PERMANENT);

  Transceiver.PrintParameters();

  //Wire.begin();

  // Inicialização do display OLED com endereço 0x3C
  if (!display.begin(SSD1306_SWITCHCAPVCC, 0x3C)) {
    Serial.println(F("SSD1306 allocation failed"));
    for (;;)
      ;
  }

  // Limpa o buffer do display
  display.clearDisplay();

  // Desenha alguns textos e formas geométricas
  display.setTextSize(1);
  display.setTextColor(SSD1306_WHITE);
  display.setCursor(0, 0);
  display.println("Master Station");
  display.display();
  delay(1500);
  display.clearDisplay();
}

int b = 0;
void loop() {
  //if (Serial2.available()) {
  if (b == 0) {
  
    StationA.Temp = 0;
    StationA.Humid = 0;
    StationA.Press = 0;
    StationA.Altitude = 0;
    StationA.Speed = 0;
    Transceiver.GetStruct(&StationA, sizeof(StationA));

    Serial.println();
    Serial.println("Received from StationA:  ");
    Serial.print("Temperature: "); Serial.print(StationA.Temp); Serial.println(" ºC");
    Serial.print("Humidy:      "); Serial.print(StationA.Humid); Serial.println(" %");
    Serial.print("Press:     "); Serial.print(StationA.Press); Serial.println(" Pa");
    Serial.print("High:       "); Serial.print(StationA.Altitude); Serial.println(" m");
    Serial.print("wind speed:  "); Serial.print(StationA.Speed); Serial.println(" m/s");
    Serial.print("Wind direc:  "); Serial.print(StationA.Direction);Serial.println(" Degrees");
    Serial.print("-------------------------------------");
    //Serial.println(Transceiver.GetAddressH());
    //Serial.print("Endereço: "); Serial.println(StationA.Adress);

    delay(100);  //just to received data before send to cloud
    
    // ====================================================================================================================================
    // --- Publicando em cada tópico ---
    StationA.Temp = 18;
    sprintf(msg, "%.2f", StationA.Temp);
    client.publish("estacao/temperatura", msg);

    sprintf(msg, "%.2f", StationA.Humid);
    client.publish("estacao/umidade", msg);

    sprintf(msg, "%.2f", StationA.Press);
    client.publish("estacao/pressao", msg);

    sprintf(msg, "%.2f", StationA.Altitude);
    client.publish("estacao/altitude", msg);

    sprintf(msg, "%.2f", StationA.Speed);
    client.publish("estacao/velocidade", msg);

    sprintf(msg, "%.2f", StationA.Direction);
    client.publish("estacao/direcao", msg);

    //Transceiver.GetStruct(&StationB, sizeof(StationB));

    // ====================================================================================================================================
    // --- Show data in display ---
    displayFunction(StationA.Temp, StationA.Humid, StationA.Speed, StationA.Altitude, StationA.Press, StationA.Direction);

    // ====================================================================================================================================
    // --- if is not connecteed to broker
    if (!client.connected()) {
      Serial.println();
      Serial.println("Connecting to MQTT");
      reconnect(Last);  //caso passe 5s retorna a receber o valor das outras estações
    }
    client.loop();
    Last = millis();
  } else { //if is not receiving data from a LoRa module
    if ((millis() - Last) > intervalSearching) {
      Serial.println();
      Serial.println("Searching data: ");
      displaySearchingData();
      Last = millis();
    }
  }
}  // end loop

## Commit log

2023-09-24 Acertando os arquivos
    [ANEMOMETRO.kicad_pcb, ANEMOMETRO.kicad_sch]
2023-09-25 exclusao de sensorBMP280
2023-09-25 changed de fotos name
2023-09-25 changed the folder name
    [ANEMOMETRO.kicad_pcb, ANEMOMETRO.kicad_sch, anemosens_mcu_v1.3_bom.xls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]
2023-09-25 changed the folder's name
    [ANEMOMETRO.kicad_pcb, ANEMOMETRO.kicad_sch, anemosens_mcu_v1.3_bom.xls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]
2024-04-23 AS5600 sensor added
    [AS5600 Breakout.kicad_pcb, AS5600 Breakout.kicad_sch, AS5600 Breakout.sch]
2024-05-13 Organização
    [AS5600 Breakout.kicad_pcb, AS5600 Breakout.kicad_sch, AS5600 Breakout.sch]
